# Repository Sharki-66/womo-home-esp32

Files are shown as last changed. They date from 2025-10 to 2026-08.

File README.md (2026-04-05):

# WoMo Home ESP32 – Bordcomputer für's Wohnmobil

> Alle wichtigen Betriebsdaten auf einen Blick – immer wissen, was im Fahrzeug los ist.

## 🚐 Worum geht es?

Wer mit dem Wohnmobil unterwegs ist, kennt das Problem: Wie viel Gas ist noch in der Flasche? Reicht der Strom? Ist der Frischwassertank bald leer? Wie kalt wird es draußen über Nacht? Die serienmäßigen Anzeigen im Fahrzeug sind oft ungenau, schlecht ablesbar oder schlicht nicht vorhanden.

**WoMo Home** ersetzt das klassische EBL-Panel durch ein selbstgebautes System, das alle Betriebsdaten des Wohnmobils erfasst, intelligent aufbereitet und auf einem 7-Zoll-Touchdisplay darstellt – jederzeit aktuell, übersichtlich und von überall im Fahrzeug erreichbar.

## 🎯 Was wird überwacht?

### Energie
- **Bordbatterie & Starterbatterie** – Spannung, Ladezustand
- **Landstrom** – Erkennung, ob 230V angeschlossen sind
- **12V-Bordnetz** – Ein/Aus per Touch, Übersicht aller Verbraucher

### Gas
- **Füllstandsmessung per Waage** – Zwei Gasflaschen, Anzeige in kg und Prozent
- **Verbrauchsberechnung** – Hochrechnung „Wie lange reicht das Gas noch?" auf Basis der letzten Stunden
- **Flaschenwechsel-Erkennung** – Automatisches Zurücksetzen beim Tausch

### Wasser
- **Frischwasser** und **Grauwasser** – Pegelstand in Prozent und Litern
- **Verbrauchstrend** – Restlaufzeit-Prognose

### Klima & Umgebung
- **Innenraumklima** – Temperatur, Luftfeuchte, Luftqualität (IAQ)
- **Außenklima** – Temperatur, Luftfeuchte, Luftdrucktrend
- **Wettervorhersage** – (todo) Aktuelles Wetter und 3-Tage-Prognose vom Internet
- **Unwetterwarnungen** – Automatisch vom europäischen Meteoalarm-System

### Navigation & Lage
- **GPS-Position** – Standort, Geschwindigkeit, Höhe über dem Router
- **Kompass & Neigung** – Fahrzeugausrichtung, Pitch/Roll (Nivellierung beim Aufstellen)
- **Reverse Geocoding** – Automatische Ortsbestimmung (z. B. „Berchtesgaden, Bayern")

### Konnektivität
- **WLAN** – Verbindung zu Campingplatz-Netzen oder Hotspots
- **LTE** – Mobiles Internet über den Router
- **Hotspot** – Eigenes WLAN für alle Geräte im Fahrzeug
- Steuerung und Statusanzeige direkt am Touchscreen

## 🏗️ Wie ist das System aufgebaut?

Das System besteht aus drei Komponenten:

**Sensorboard** – Ein kleiner Mikrocontroller, der sämtliche Sensoren und Aktoren bedient: Waagen, Temperatursensoren, Batteriespannungen, Tankpegel, Kompass. Er sitzt versteckt hinter dem EBL-Schrank und ersetzt dort das originale Anzeigepanel.

**Touchdisplay** – Ein 7-Zoll-Farbbildschirm mit Touch, eingebaut an einer gut sichtbaren Stelle. Hier laufen alle Informationen zusammen und werden grafisch aufbereitet. Über den Touchscreen lassen sich auch Funktionen steuern (Bordnetz ein/aus, Radio, WLAN).

**Router** – Hier ein Teltonika RUTX11 sorgt für die Verbindung zur Außenwelt: LTE-Internet unterwegs, WLAN auf dem Campingplatz, GPS-Ortung und ein eigener Hotspot für Laptops und Smartphones an Bord. Wurde gewählt wegen der Anschlußmöglichkeiten der Antennen auf dem Womo Dach.

Sensorboard und Display kommunizieren über einen RS485-Bus

## 💡 Warum selbst bauen?

- **Genauigkeit** – Die Gasflaschen-Waage zeigt den Füllstand in Gramm statt „irgendwo zwischen halb und voll". Die Tankpegel werden kalibriert statt geschätzt.
- **Alles an einem Ort** – Kein Aufstehen mehr, um am EBL-Panel nachzuschauen. Kein separates Thermometer, keine Extra-App für den Router.
- **Intelligente Prognosen** – Das System rechnet mit: Wie lange reicht das Gas bei aktuellem Verbrauch? Wann ist der Tank leer? Wie entwickelt sich der Luftdruck?
- **Offenes System** – Komplett Open Source auf ESP32-Basis. Erweiterbar, anpassbar, reparierbar. Kein Cloud-Zwang, keine Abo-Kosten.
- **Robustheit** – Industriekomponenten (RS485, Metallgehäuse-Router), für den 12V-Betrieb ausgelegt. Funktioniert auch ohne Internet.
- **Weil es Spass macht und so noch nicht gibt.**

## 📁 Projektstruktur

```
womo-home-esp32/
├── firmware/
│   ├── display/            ← Firmware für das Touchdisplay
│   └── sensorboard/        ← Firmware für das Sensorboard
├── hardware/
│   ├── schematics/          ← Schaltpläne
│   └── datasheets/          ← Datenblätter der Komponenten
├── docs/                    ← Ausführliche Dokumentation
└── tests/                   ← Einzelne Hardware-Tests
```

Technische Details (Pinbelegungen, Protokoll, Build-Anleitung) finden sich in den jeweiligen Unterordnern und in [docs/README.md](docs/README.md).

## 🔧 Entwicklung

Das Projekt nutzt das [Espressif ESP-IDF](https://docs.espressif.com/projects/esp-idf/en/stable/esp32s3/get-started/) Framework. Für jeden Firmware-Teil gibt es einen eigenen VS Code Workspace mit vorkonfigurierten Build/Flash/Monitor-Tasks:

- `womo-sensor.code-workspace` – Sensorboard-Entwicklung
- `womo-display.code-workspace` – Display-Entwicklung

**!!! Der gesammte Code wurde im Vibe Coding erzeugt !!!**

## 📜 Lizenz

Privates Projekt. Siehe [LICENSE](LICENSE).

## 📸 Aufbau-Fotos (Feb 2026)

| Display (Vorderseite) | Sensorboard (Rückseite) |
|---|---|
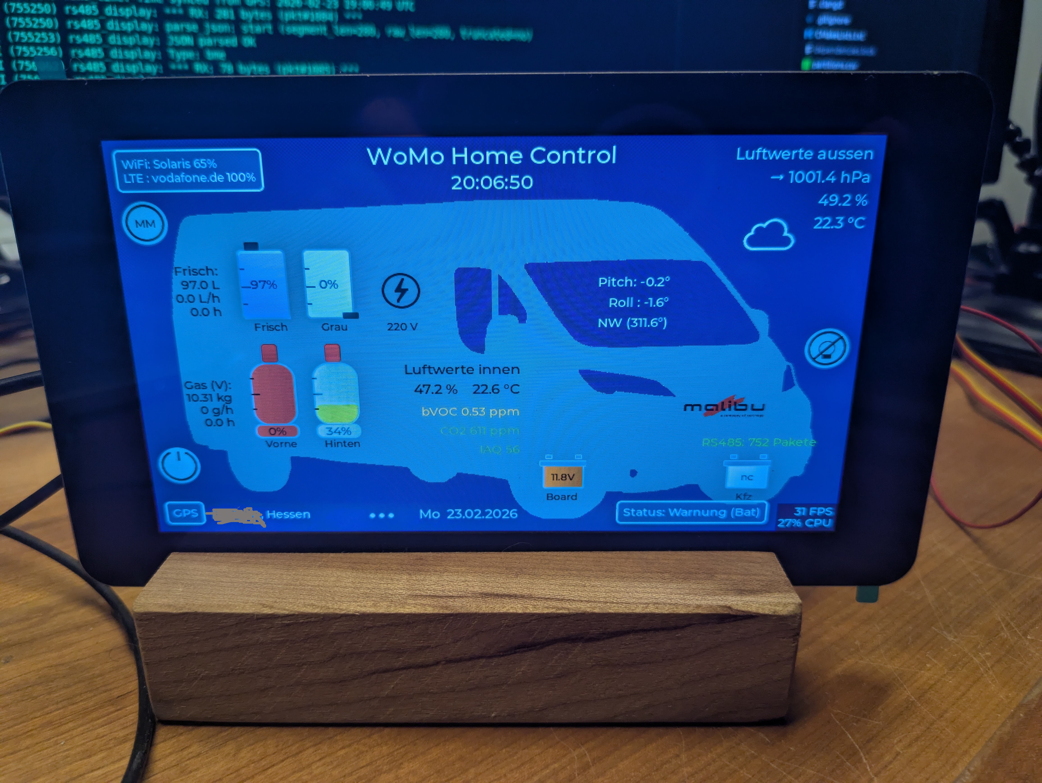
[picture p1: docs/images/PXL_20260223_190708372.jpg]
Display Vorderseite
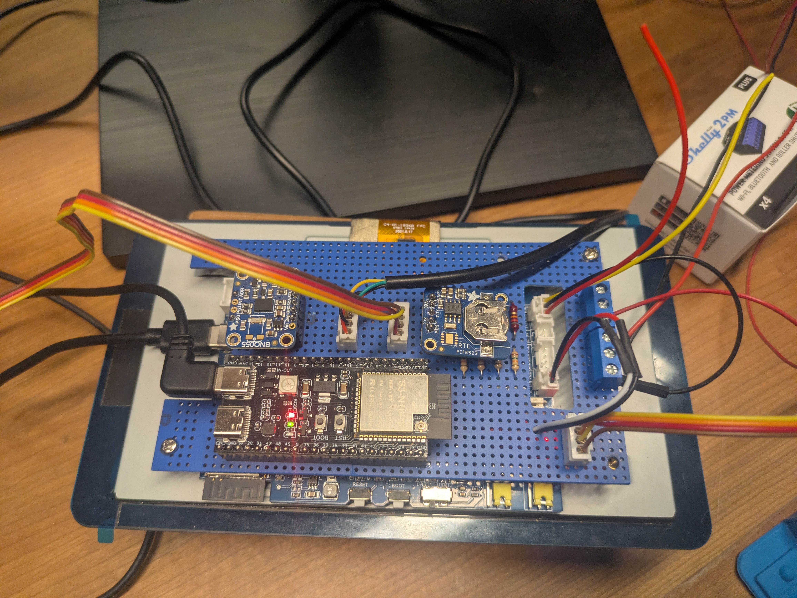
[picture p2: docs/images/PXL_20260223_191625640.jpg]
Sensorboard Rückseite
|  |  |

## 🖥️ Display-Screenshots

| Nacht-Ansicht | GPS |
|---|---|
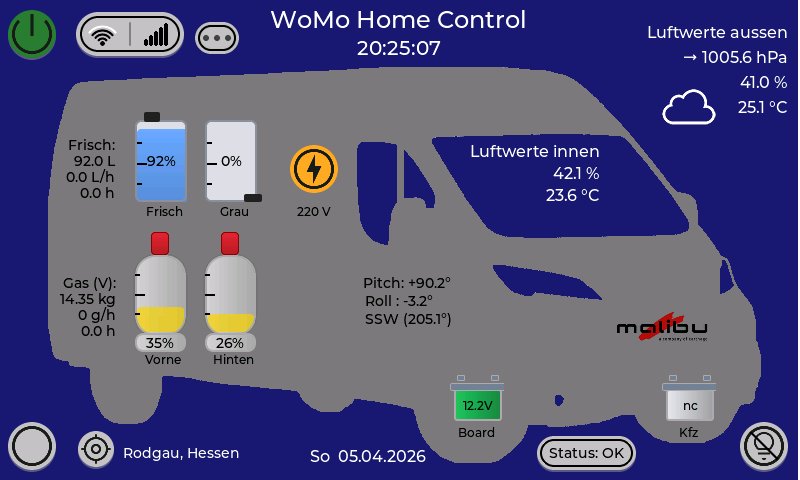
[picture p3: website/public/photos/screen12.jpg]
Nacht-Ansicht
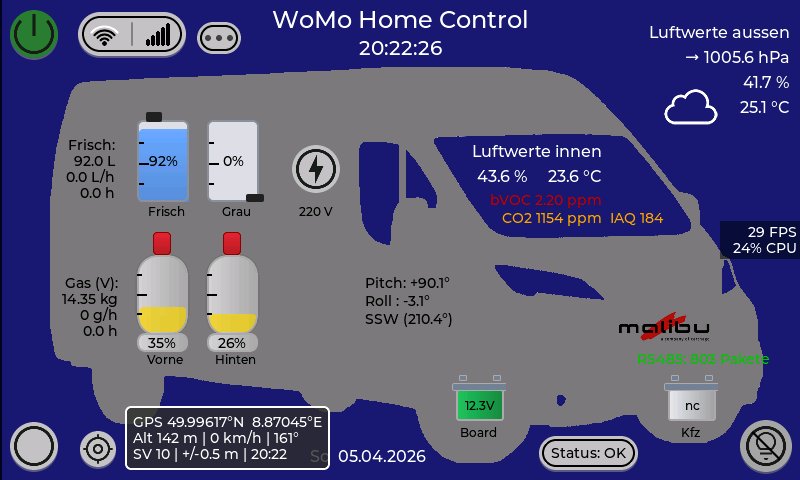
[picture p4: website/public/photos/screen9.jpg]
GPS
|  |  |

| Wetter | Einstellungen |
|---|---|
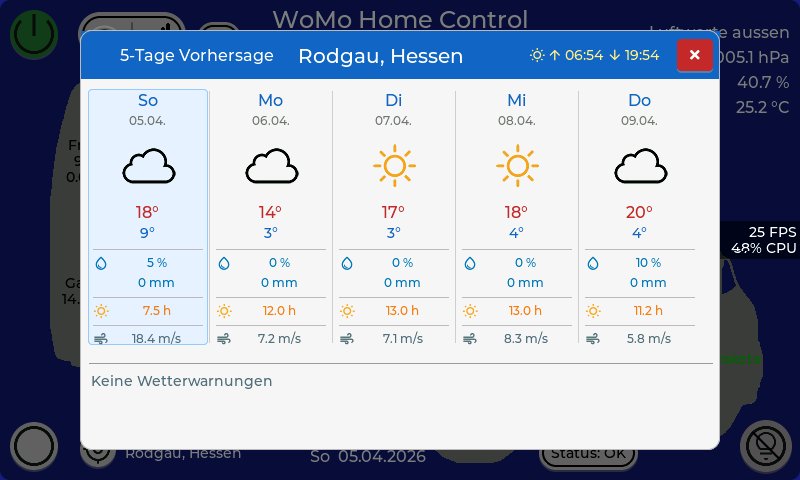
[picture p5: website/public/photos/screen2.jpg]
Wetter
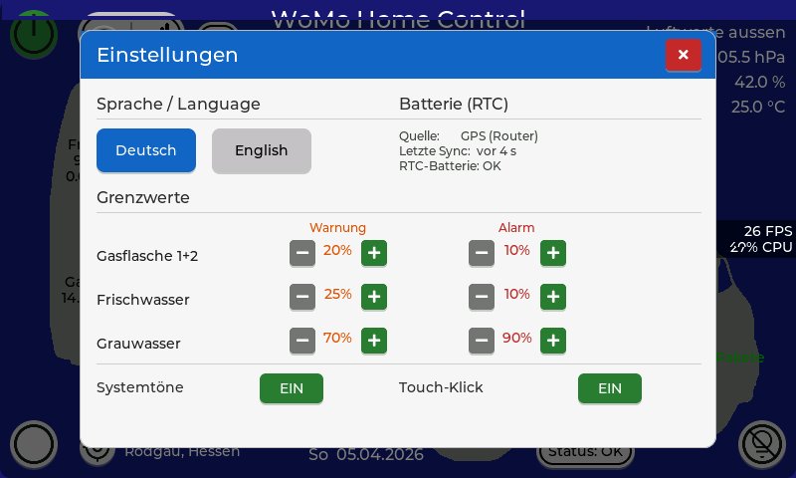
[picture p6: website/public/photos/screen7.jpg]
Einstellungen
|  |  |

| Gas wechseln | Nivellieren |
|---|---|
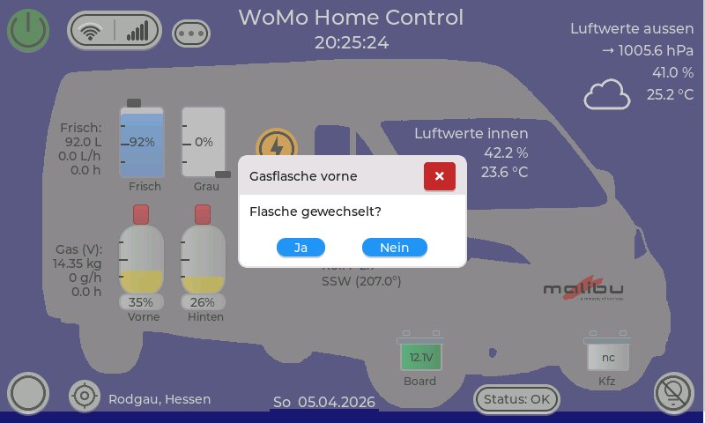
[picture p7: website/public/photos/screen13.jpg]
Gas wechseln
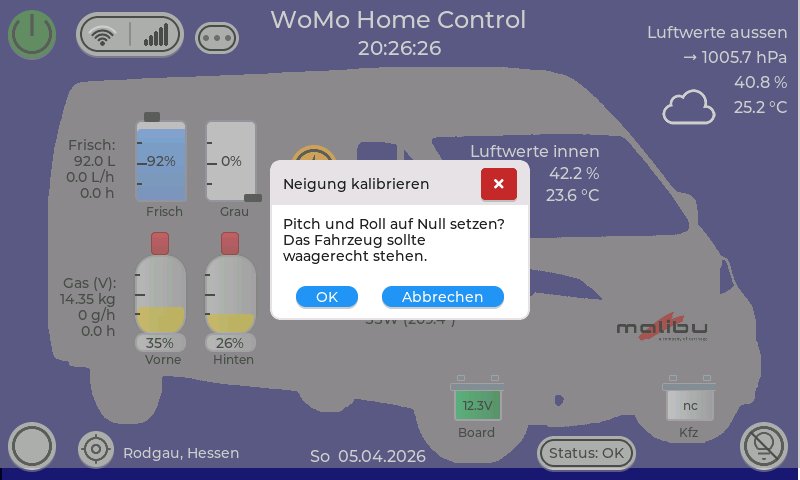
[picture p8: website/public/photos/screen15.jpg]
Nivellieren
|  |  |

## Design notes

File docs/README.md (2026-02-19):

# Dokumentation – WoMo Home ESP32

## Hardware

| Dokument | Beschreibung |
|---|---|
| [ESP32-S3-Touch-LCD-7](hardware/esp32-s3-touch-lcd-7.md) | Waveshare Display-Board (800×480, GT911 Touch) |
| [LCD-Spezifikationen](hardware/WAVESHARE_ESP32_S3_LCD_SPECS.md) | Display-Panel, RGB-Interface, Timing |
| [ESP32-S3 Modul-Specs](hardware/WAVESHARE_ESP32_S3_SPECS.md) | ESP32-S3-WROOM-1, Pinout, PSRAM |
| [Verifizierte Specs](hardware/WAVESHARE_ESP32_S3_VERIFIED_SPECS.md) | Aus Demo-Code bestätigte Werte |

## Firmware

| Dokument | Beschreibung |
|---|---|
| [Sensorboard README](../firmware/sensorboard/README.md) | Hardware, Pins, RS485-Protokoll, NVS, Projektstruktur |
| [Display README](../firmware/display/README.md) | Hardware, Funktionen, Externe APIs, Projektstruktur |

## System

| Komponente | Hardware | Funktion |
|---|---|---|
| **Display** | Waveshare ESP32-S3-Touch-LCD-7 | LVGL-GUI, Touch, RS485-Empfang, Router-Anbindung |
| **Sensorboard** | Heemol ESP32-S3 N16R8 DevKitC-1 | Sensoren (BME680, BNO055, HX711, ADC), RS485-Sender |
| **Router** | Teltonika RUTX11 | WLAN, LTE, GNSS, Hotspot |

Kommunikation: Display ↔ Sensorboard per RS485 (JSON, 115200 8N1).
Router wird vom Display per HTTP/UCI angesprochen.

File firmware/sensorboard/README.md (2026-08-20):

# WoMoHome Sensorboard Firmware

ESP-IDF v5.5.2 · ESP32-S3-WROOM-1 (N16R8)

## Hardware

| Komponente | Beschreibung | Bus / Pin |
|---|---|---|
| **MCU** | Heemol ESP32-S3 N16R8 DevKitC-1 | — |
| **IMU** | BNO055 – Lage, Kompass, Kalibrierung | I2C 0x28 |
| **Klima innen** | BME680 – Temp, Feuchte, Druck, IAQ (BSEC 3.3V) | I2C 0x76 |
| **Klima außen** | BME280 oder BME260 – Temp, Feuchte, Druck, Trend (1h/3h) | I2C 0x77 |
| **Gasfüllstand** | HX711 – 2× Wägezelle (Kanal A + B) | DOUT=GPIO47, SCK=GPIO45 |
| **GasBee** | BLE-Gaswaage (ESP32-C3) – NimBLE Central, Auto-Reconnect | BLE |
| **INA226** | Strom-/Leistungsmessung Hauptleitung (Vbus 0–36V, ±81,92mV Shunt) | I2C 0x40 |
| **Batterien** | 2× ADC mit Spannungsteiler | Kfz=GPIO4, Board=GPIO5 |
| **Tanks** | 2× Votronic kapazitiv (0–1V) | Frisch=GPIO1 (100L), Grau=GPIO2 (92L) |
| **RTC** | PCF8523 – Echtzeituhr | I2C 0x68 |
| **RS485** | MAX3485, Half-Duplex, 57600 8N1 | TX=GPIO9, RX=GPIO10, DE=GPIO8 |
| **I2C** | 100 kHz, interne Pull-ups | SDA=GPIO16, SCL=GPIO15 |
| **RGB-LED** | WS2812 (onboard) | GPIO48 |

### Steuer-/Sense-GPIOs

| GPIO | Funktion | Richtung |
|---|---|---|
| 7  | Display 5V (P-MOSFET Q4: LOW=ein, Hi-Z=aus) | Ausgang |
| 11 | 12V Bordnetz EIN (bistabiles Relais, Puls) | Ausgang |
| 12 | 12V Bordnetz AUS (bistabiles Relais, Puls) | Ausgang |
| 13 | Multimedia Power (N-MOSFET, HIGH=ein) | Ausgang |
| 14 | 12V Bordnetz Feedback | Eingang |
| 21 | 230V AC Sense | Eingang |

### Spannungsteiler (ADC)
Alle Batterie-/Sense-Kanäle: **100 kΩ / 22 kΩ** Teiler → Faktor 122/22.
- Batterien: 12V → ~2,17V am ADC (BZV55B3V3 Zener-Schutz)
- Tanks: Votronic 0–1V → direkt am ADC, 0–1000 mV = 0–100%
- Nicht angeschlossen: < 1V → `nc=true`

## RS485-Protokoll (Topic-basiert, v2)
CRLF-terminierte ASCII-JSON-Zeilen. Round-Robin, max. 1 Topic pro 100 ms. Nach `display_ready`: Initial-Burst aller Topics sofort.

| Topic | Intervall | Felder |
|---|---|---|
| `hello` | bis ready | `fw`, `board`, `uptime`, `ts` |
| `hb` | 30 s | `uptime`, `ts`, `heap` |
| `ctrl` | 2 s | `pwr_on`, `radio_on`, `ac_present`; optional: `rtc_bat_low`, `rtc_bat_switched` |
| `imu` | 5 s | `yaw_deg`, `pitch_deg`, `roll_deg`, `hdg`, `cal:{sys,gyro,acc,mag}`, `calibrated`, `ts` |
| `bat` | 10 s | `b1`, `b2` (Volt), `nc1`, `nc2` |
| `tank` | 10 s | `t1`, `t2` (%), `nc1`, `nc2`, `t1_l`, `t2_l` (Liter), `t1_rate1h`, `t1_rate2h`, `t1_rest_h`, `t2_rate1h`, `t2_rate2h`, `t2_rest_h` |
| `hx` | 10 s | `a`, `b` (kg, optional), `sum` (optional), `nc`, `ts` |
| `gas` | 10 s | `active`, `net`, `rate1h`, `rate2h`, `rest_h`, `net_a`, `net_b`, `cap_kg`, `pct`, `pct_a`, `pct_b` |
| `bme_in` | 15 s | `chip` (`bme680`/`bme280`/`bme260`/`ruuvi`), `addr`?, `temp_c`, `rh_pct`, `press_hpa`, `ts`; BME680 zusätzlich: `gas_kohm`?, `iaq`, `iaq_acc`, `eco2_ppm`, `bvoc_ppm`; bei Ruuvi-Fallback zusätzlich `batt_mv`? |
| `bme_out` | 15 s | `chip`, `addr`?, `temp_c`, `rh_pct`, `press_hpa`, `ts`, `press_trend_state`?, `press_trend_hpa_h`?, `gas_kohm`?; bei Ruuvi-Fallback zusätzlich `batt_mv`? |
| `elec` | 5 s | `v_bus` (V), `i_a` (A), `p_w` (W), `v_shunt_mv` (mV), `ts`; `nc=true` wenn INA226 nicht gefunden |

**`press_trend_state`-Werte:** `fall_fast` / `fall_slow` / `steady` / `rise_slow` / `rise_fast`
(bevorzugt 3h-Fenster, Fallback 1h; ab 4 bzw. 12 Samples à 15 min verfügbar)

**WiFi-Passwort-Anfrage:** Bei fehlenden WLAN-Zugangsdaten sendet das Sensorboard `type:"wifi_pass_request"` per RS485.

## Web-Dashboard (HTTP, Port 80)

Erreichbar unter `http://Womo-Sensor.local/` nach WiFi-Verbindung mit RUTX11.

| Endpunkt | Methode | Beschreibung |
|---|---|---|
| `/` | GET | Weiterleitung auf `/dashboard.html` |
| `/dashboard.html` | GET | Vollständiges Steuer- und Sensor-Dashboard |
| `/horizon.html` | GET | Horizont-/Parkhilfe-Anzeige |
| `/api/status` | GET | Systemstatus (JSON) |
| `/api/data` | GET | Aktueller Sensor-Snapshot (JSON) |
| `/api/imu` | GET | IMU-Snapshot (JSON) |
| `/api/cmd` | POST | Steuerkommandos (JSON, gleiche `cmd`-Syntax wie RS485) |

Statische Dateien (HTML, PNG, favicon) werden aus der SPIFFS-Partition `storage` → `/spiffs` geladen.

## NVS-Namespaces

| Namespace | Key(s) | Inhalt |
|---|---|---|
| `bno055` | `calib`, `pr_zero` | Kalibrierungsoffsets, Pressure-Zero |
| `bme680` | `press_hist` | Luftdruck-Historie (96 Samples / 24h) |
| `bsec` | `state_in_<addr>_v<n>` | BSEC IAQ State (sensorspezifisch, z.B. `state_in_76_v3`) |
| `gas_state` | `gas` | Gasverbrauch (Raten, Tare, Flaschentausch) |
| `tank_state` | `tank1`, `tank2` | Tank-Verbrauchsraten |
| `wifi_cfg` | `ssid`, `pass` | WLAN-Zugangsdaten (RUTX11) |

> **INA226 Kalibrierung:** `SENSOR_INA226_SHUNT_MOHM` in `sensor_config.h` auf den verbauten Shunt-Widerstand (mΩ) setzen. `SENSOR_INA226_MAX_CURRENT_A` bestimmt die Auflösung (Current_LSB = MAX_CURRENT / 32768 A). Maximale Shuntspannung: ±81,92 mV → I_max = 81,92 mV / R_shunt.

> **BSEC State Version:** Bei Tausch des Indoor-BME680 `SENSOR_BME680_BSEC_STATE_VERSION` in `sensor_config.h` hochzählen, damit kein alter Baseline-State auf den neuen Sensor angewandt wird.

## Projektstruktur

```
main/
├── app_main.c              Startup, Task-Orchestrierung
├── sensor_config.h         Pin-Belegung, Kalibrierung, Konstanten
├── hal/
│   ├── sensor_i2c_bus      I2C-Bus Init
│   └── deep_sleep          Touch-Wakeup, Deep-Sleep
├── sensors/
│   ├── analog_sensor       ADC (Batterien, Tanks), Median-of-3-Mittelung
│   ├── bme680_sensor       BME680/BME280/BME260 + BSEC + Drucktrend
│   ├── bno055_sensor       IMU + Kalibrierung
│   ├── hx711_sensor        Wägezellen (Gas)
│   └── ina226_sensor       INA226 Strom-/Leistungsmessung Hauptleitung
├── network/
│   ├── rs485_modem         JSON-Serialisierung aller Topics, Steuerlogik
│   ├── womo_rs485          UART-Transport, Framing, ACK
│   ├── gasbee_ble_client   NimBLE Central – BLE-Gaswaage GasBee
│   └── wifi/
│       ├── sensor_wifi     STA-Verbindung (RUTX11), NVS-Credentials
│       └── sensor_http     HTTP-Server (Dashboard, Parkhilfe, API)
└── time/
    ├── rtc_pcf8523         RTC-Treiber (PCF8523)
    └── time_sync           NTP + RTC-Sync
```

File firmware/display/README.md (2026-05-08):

# WoMoHome Display Firmware

ESP-IDF v5.5.2 · LVGL v9.5 · ESP32-S3 (Waveshare ESP32-S3-Touch-LCD-7)

## Hardware

| Komponente | Beschreibung |
|---|---|
| **Board** | Waveshare ESP32-S3-Touch-LCD-7 (800×480, RGB565) |
| **MCU** | ESP32-S3-WROOM-1, 16 MB Flash, 8 MB PSRAM (Octal) |
| **Display** | 7" IPS, ST7701 RGB-Interface, Double-Buffer + Direct-Mode |
| **Touch** | GT911 (I2C), CH422G GPIO-Expander für Backlight/Reset |
| **RS485** | RX/TX Sensorboard (JSON, 57600 8N1, Half-Duplex) |
| **SD-Karte** | Hintergrundbilder, optional |

## Funktionen

- **Hauptscreen**: Temperatur (innen/außen), Luftdruck + Trend-Pfeil, Feuchte, Kompass, Neigung
- **Batterien**: 2× Balken mit Spannung, Warnung bei Unterspannung
- **Tanks**: Frischwasser + Grauwasser mit Füllstand, Verbrauchsrate, Restdauer
- **Gas**: 2× Flaschengewicht, aktiver Verbrauch, Restdauer
- **Wetter**: Aktuelles WMO-Symbol + Temperatur (Open-Meteo), Tipp auf Icon → 5-Tage-Vorhersage-Modal; Auto-Popup bei Unwetterwarnungen (Meteoalarm)
- **Sonnenauf-/-untergang**: Berechnung aus GPS-Position (womo_sun_calc), Anzeige im Hauptscreen
- **Konnektivität**: Modal mit AP-Status, WLAN-Scan/Connect, LTE Ein/Aus (Router UCI)
- **Router-LEDs**: Separate Statusanzeige für WLAN/LTE/GPS-Empfang des Routers
- **Steuerung**: 12V Bordnetz + Multimedia per RS485-Kommandos ans Sensorboard
- **Fehler-Management**: Fehler-Stack mit Latching, Quittierung per Touch, Buzzer-Alarm (Warn/Alarm-Ton bei neuen unquittier­ten Fehlern)
- **Einstellungs-Modal**: Schwellwerte für Tank/Batterie/Gas konfigurierbar, Speicherung in NVS
- **Screenshot**: Long-Press unten links → PNG auf SD-Karte
- **Tag/Nacht**: Automatischer Themenwechsel (Sonnenauf-/-untergang), Backlight-Steuerung

## Externe Anbindungen

| Dienst | Zweck | TLS |
|---|---|---|
| Open-Meteo | Aktuelles Wetter + 5-Tage-Vorhersage | ISRG Root X1 (PEM, eingebettet) |
| Nominatim | Reverse Geocoding | ISRG Root X1 (PEM, eingebettet) |
| Meteoalarm | Unwetterwarnungen | GEANT TLS RSA 1 (PEM, eingebettet) |
| Teltonika RUTX11 | WLAN/LTE/GPS-Steuerung | HTTP (LAN) |

## Projektstruktur

```
main/
├── main.c                      Startup, GUI-Update-Loop, Task-Orchestrierung
├── gui/
│   ├── womo_theme              Tag/Nacht-Umschaltung
│   ├── womo_locale             Deutsche Lokalisierung (Datum, Wochentage)
│   ├── womo_fonts_german       6× Montserrat mit dt. Sonderzeichen + Icons
│   ├── womo_battery            Batterie-Widget
│   ├── womo_tank               Tank-Widget
│   ├── womo_gas_bottle         Gas-Flaschen-Widget
│   ├── womo_weather            Wetter-Icon-Mapping (WMO → LVGL)
│   ├── womo_forecast_modal     5-Tage-Vorhersage Modal (Open-Meteo daily)
│   ├── womo_connectivity_modal WLAN/LTE/AP-Steuerung
│   ├── womo_router_leds_modal  Router-LED-Statusanzeige
│   ├── womo_settings_modal     Einstellungs-Modal (Schwellwerte, NVS)
│   └── womo_thresholds         Schwellwert-Verwaltung (NVS-Persistenz)
├── hardware/
│   ├── waveshare_rgb_lcd_port  LCD + Touch + CH422G Init
│   ├── lvgl_port               LVGL Flush, Buffer, Task, Indev
│   └── buzzer                  Piezo-Buzzer (Warn/Alarm-Töne)
├── network/
│   ├── womo_wifi               STA-Verbindung + NVS-Passwort-Speicher (RUTX11)
│   ├── womo_weather_http       Open-Meteo API (aktuell + 5-Tage daily)
│   ├── womo_geocode            Nominatim Reverse Geocoding
│   ├── womo_meteoalarm         Meteoalarm CAP-Feed
│   ├── womo_router_uci         RUTX11 UCI JSON-RPC
│   ├── womo_buzzer_http        HTTP-Endpunkt für externen Buzzer-Trigger
│   ├── womo_http_mutex         TLS-Session-Serialisierung
│   ├── isrg_root_x1_pem.h     Let's Encrypt Root-Zertifikat
│   └── harica_root_pem.h       GEANT TLS RSA 1 (Meteoalarm)
├── rs485/
│   └── womo_rs485_display      RS485-Empfang/Senden, JSON-Parsing, Merge-Snapshot
├── storage/
│   └── womo_sd                 SD-Karten-Zugriff (Hintergrundbilder, Screenshots)
└── time/
    ├── womo_time               SNTP + RTC-Sync
    └── womo_sun_calc           Sonnenauf-/-untergang aus GPS-Koordinaten
```

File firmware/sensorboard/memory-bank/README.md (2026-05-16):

# Memory Bank – WoMoHome Sensorboard

Persistenter Projektkontext für Claude Code Sessions.

## Lesreihenfolge
1. [projectbrief.md](projectbrief.md) – Ziel, Scope, Hardware-Übersicht
2. [productContext.md](productContext.md) – Rolle im Gesamtsystem, Schnittstellen
3. [techContext.md](techContext.md) – Build, Komponenten, GPIO-Besonderheiten, NVS
4. [systemPatterns.md](systemPatterns.md) – Boot-Sequenz, Tasks, Protokoll, Sensor-Muster
5. [activeContext.md](activeContext.md) – Aktueller Branch, offene TODOs, Kalibrierungen
6. [progress.md](progress.md) – Fertig / In Arbeit / Bekannte Probleme

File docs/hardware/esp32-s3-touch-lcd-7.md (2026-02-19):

# ESP32-S3-Touch-LCD-7 (Waveshare)

Kurzübersicht des Boards basierend auf den Waveshare-Wiki-Informationen und den bereits kopierten Inhalten.

## Bilder
- Onboard-Ressourcen (beschriftet): Onboard-Ansicht

## Kernmerkmale
- ESP32-S3-WROOM-1-N16R8 (16 MB Flash, 8 MB PSRAM, 512 KB SRAM, 384 KB ROM), LX7 Dual-Core bis 240 MHz.
- 7" IPS, 800×480, 65k Farben, kapazitiver Touch (5-Punkt, I²C, Interrupt).
- WLAN 2.4 GHz b/g/n, BLE 5 (onboard Antenne).
- Schnittstellen: CAN, RS485, I²C, UART (umschaltbar), TF/SD, USB Full-Speed (OTG), PH2.0 Li-Ion (Boost auf 5 V, Laderegler CS8501).
- CH422G IO-Expander steuert u. a. Backlight, Touch-Reset, SD-CS, USB/CAN-Select.

## Onboard-Ressourcen (Nummern aus der Waveshare-Grafik)
1. ESP32-S3-WROOM-1-N16R8 (8 MB PSRAM, 16 MB Flash)
2. Display-FPC (LCD)
3. Touch-FPC
4. TF/SD-Slot
5. USB Type-C (USB-OTG)
6. USB-UART Type-C
7. UART-Klemmen (gemeinsam mit 6, umschaltbar per Schalter 15)
8. Sensor-Klemme
9. CAN-Klemme
10. I²C-Klemme
11. RS485-Klemme + Backlight-Boost
12. PH2.0 Li-Ion-Eingang (3.7 V), Boost auf 5 V, Ladestrom via R45 konfigurierbar
13. CAN-Abschlusswahl
14. RS485-Abschlusswahl
15. UART-Select (UART1 / UART2)
16. BOOT-Taster
17. RESET-Taster
18. I²C-Level-Translator (3.3 V / 5 V)
19. DONE (Laden fertig)
20. CHG (Ladevorgang)
21. PWR (Power-LED)

## Pinbelegungen (Auszug)
### LCD (RGB + Sync + Backlight)
- VSYNC: GPIO3
- HSYNC: GPIO46
- PCLK: GPIO7
- DE: GPIO5
- Daten: R3–R7 (GPIO1,2,40,41,42), G2–G7 (GPIO39,45,48,47,21), B3–B7 (GPIO14,38,18,17,10)
- Backlight Enable: CH422G EXIO2 (Druckpunkt DISP)

### Touch (I²C)
- TP_IRQ: GPIO4
- TP_SDA: GPIO8
- TP_SCL: GPIO9
- TP_RST: CH422G EXIO1

### USB (OTG/Device)
- USB_D−: GPIO19
- USB_D+: GPIO20
- USB_SEL: CH422G EXIO5 (Low = USB, sonst CAN)

### TF/SD (SPI)
- MOSI: GPIO11
- SCK: GPIO12
- MISO: GPIO13
- SD_CS: CH422G EXIO4 (Low aktiv)

### RS485
- TXD: GPIO15
- RXD: GPIO16
- Auto-DE/RE-Schaltung onboard

### CAN
- CANTX: GPIO20
- CANRX: GPIO19
- CAN_SEL: CH422G EXIO5 (High = CAN, sonst USB)

### I²C (Shared Bus)
- SDA: GPIO8
- SCL: GPIO9
- Nutzung: Touch, CH422G IO-Expander, externe I²C-Buchse

### Stromversorgung
- PH2.0 Li-Ion 3.7 V, Boost auf 5 V (CS8501, ca. 580 mA Standard-Ladestrom; änderbar via R45).
- LEDs: DONE (voll), CHG (Lädt), PWR (Versorgt).

## Hinweise
- Touch-Reset, SD-CS, Backlight und USB/CAN-Select laufen über den CH422G – immer dessen Pegel berücksichtigen.
- USB/CAN teilen sich GPIO19/20; EXIO5 entscheidet den Modus.
- Backlight Enable über EXIO2 (aktiviert/abschaltet Versorgung des Panels).
- Bei eigener Verkabelung: Level-Translator (Punkt 18) kann 3.3 V oder 5 V bereitstellen.

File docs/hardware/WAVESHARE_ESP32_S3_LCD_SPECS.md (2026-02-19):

# Hardware-Spezifikationen - Waveshare ESP32-S3 Touch LCD 7" - 800×480

## 📋 **OFFIZIELLE DOKUMENTATIONS-QUELLEN**

### **Primäre Quellen (Waveshare offiziell)**
- 📄 **Wiki:** https://www.waveshare.com/wiki/ESP32-S3-Touch-LCD-7
- 📥 **Schematic (PDF):** https://www.waveshare.com/w/upload/4/4e/ESP32-S3-Touch-LCD-7_Schematic.pdf
- 📚 **User Manual (PDF):** https://files.waveshare.com/upload/2/2a/ESP32-S3-Touch-LCD-7_User_Manual_EN.pdf
- 🔧 **GitHub Examples:** https://github.com/waveshare/ESP32-S3-Touch-LCD-7
- 🛒 **Product Page:** https://www.waveshare.com/esp32-s3-touch-lcd-7.htm

## ✅ **VERIFIZIERTE HARDWARE-SPEZIFIKATIONEN**

### 📺 **DISPLAY SPEZIFIKATIONEN**

| Spezifikation | Wert |
|---|---|
| **Display Typ** | IPS LCD |
| **Display Controller** | ST7262 |
| **Interface** | RGB (16-bit parallel) |
| **Auflösung** | 800×480 Pixel |
| **Diagonale** | 7 Zoll |
| **Pixel Clock** | 16 MHz |
| **Color Depth** | 16-bit (RGB565) |
| **Data Width** | 16-bit parallel |
| **Viewing Angle** | IPS 170° |

### 👆 **TOUCH CONTROLLER**

| Spezifikation | Wert |
|---|---|
| **Controller IC** | GT911 |
| **Interface** | I2C |
| **Touch Points** | 5-Point Multi-Touch |
| **I2C Address** | 0x5D oder 0x14 |

### 🔌 **ESP32-S3 SPEZIFIKATIONEN**

| Spezifikation | Wert |
|---|---|
| **MCU** | ESP32-S3-WROOM-1-N8R8 |
| **Flash** | 8MB |
| **PSRAM** | 8MB |
| **WiFi** | 802.11 b/g/n |
| **Bluetooth** | Bluetooth 5.0, BLE |
| **USB** | USB-C (Programming + Power) |

## ⚙️ **GPIO PIN-MAPPING**

### **RGB Interface GPIO Pins:**
```c
#define EXAMPLE_LCD_IO_RGB_VSYNC        (GPIO_NUM_3)
#define EXAMPLE_LCD_IO_RGB_HSYNC        (GPIO_NUM_46)
#define EXAMPLE_LCD_IO_RGB_DE           (GPIO_NUM_5)
#define EXAMPLE_LCD_IO_RGB_PCLK         (GPIO_NUM_7)

// RGB Data Lines (16-bit)
#define EXAMPLE_LCD_IO_RGB_DATA0        (GPIO_NUM_14)  // R0
#define EXAMPLE_LCD_IO_RGB_DATA1        (GPIO_NUM_38)  // R1
#define EXAMPLE_LCD_IO_RGB_DATA2        (GPIO_NUM_18)  // R2
#define EXAMPLE_LCD_IO_RGB_DATA3        (GPIO_NUM_17)  // R3
#define EXAMPLE_LCD_IO_RGB_DATA4        (GPIO_NUM_10)  // R4
#define EXAMPLE_LCD_IO_RGB_DATA5        (GPIO_NUM_39)  // G0
#define EXAMPLE_LCD_IO_RGB_DATA6        (GPIO_NUM_0)   // G1
#define EXAMPLE_LCD_IO_RGB_DATA7        (GPIO_NUM_45)  // G2
#define EXAMPLE_LCD_IO_RGB_DATA8        (GPIO_NUM_48)  // G3
#define EXAMPLE_LCD_IO_RGB_DATA9        (GPIO_NUM_47)  // G4
#define EXAMPLE_LCD_IO_RGB_DATA10       (GPIO_NUM_21)  // G5
#define EXAMPLE_LCD_IO_RGB_DATA11       (GPIO_NUM_1)   // B0
#define EXAMPLE_LCD_IO_RGB_DATA12       (GPIO_NUM_2)   // B1
#define EXAMPLE_LCD_IO_RGB_DATA13       (GPIO_NUM_42)  // B2
#define EXAMPLE_LCD_IO_RGB_DATA14       (GPIO_NUM_41)  // B3
#define EXAMPLE_LCD_IO_RGB_DATA15       (GPIO_NUM_40)  // B4
```

### **Touch I2C GPIO Pins:**
```c
#define I2C_MASTER_SCL_IO           9       // I2C Clock
#define I2C_MASTER_SDA_IO           8       // I2C Data
#define I2C_MASTER_NUM              0       // I2C Port 0
#define I2C_MASTER_FREQ_HZ          400000  // 400kHz
#define GPIO_INPUT_IO_4             4       // Touch interrupt pin
```

### **Backlight & Control:**
```c
#define EXAMPLE_PIN_NUM_BK_LIGHT        (-1)    // Hardware-gesteuert
#define EXAMPLE_LCD_IO_RST              (-1)    // Nicht verwendet
#define EXAMPLE_LCD_IO_RGB_DISP         (-1)    // Nicht verwendet
```

## 🛠️ **SOFTWARE-KONFIGURATION**

### **ESP-IDF Version:**
```
ESP-IDF v5.2.0+ (empfohlen)
```

### **LVGL Konfiguration für 800×480:**
```c
#define LVGL_PORT_H_RES             800
#define LVGL_PORT_V_RES             480
#define LVGL_PORT_BUFFER_HEIGHT     100
#define LVGL_PORT_AVOID_TEAR        1
```

### **RGB Interface Timing:**
```c
.timings = {
    .pclk_hz = 16000000,        // 16MHz Pixel Clock
    .h_res = 800,               // Horizontale Auflösung
    .v_res = 480,               // Vertikale Auflösung
    .hsync_pulse_width = 30,
    .hsync_back_porch = 16,
    .hsync_front_porch = 210,
    .vsync_pulse_width = 13,
    .vsync_back_porch = 10,
    .vsync_front_porch = 22,
}
```

## 🔋 **STROMVERSORGUNG**

| Spezifikation | Wert |
|---|---|
| **Input Voltage** | 5V via USB-C |
| **Power Consumption** | ~1.2W (Display an) |
| **Sleep Current** | <10mA |

## 📦 **VERWENDETE BIBLIOTHEKEN**

### **ESP-IDF Komponenten:**
- `esp_lcd_panel_rgb` - RGB LCD Panel Treiber
- `esp_lcd_touch_gt911` - GT911 Touch Controller Treiber
- `driver/i2c` - I2C Treiber für Touch
- `driver/gpio` - GPIO Treiber

### **LVGL Integration:**
- RGB Avoid Tearing implementiert
- Double Buffering für flüssige Animationen
- 800×480 optimierte Widgets

## ✅ **VERIFIKATIONS-STATUS**

| Komponente | Status | Quelle |
|---|---|---|
| **Display Controller (ST7262)** | ✅ Verifiziert | Waveshare Dokumentation |
| **Touch Controller (GT911)** | ✅ Verifiziert | Waveshare Demo Code |
| **Auflösung 800×480** | ✅ Verifiziert | Hardware-Spezifikation |
| **GPIO Pin-Mapping** | ✅ Verifiziert | Schaltplan |
| **ESP-IDF v5.2.0** | ✅ Verifiziert | Offizieller Support |
| **LVGL Integration** | ✅ Verifiziert | Funktionierender Demo |
| **RGB 16-bit Interface** | ✅ Verifiziert | Hardware-Konfiguration |
| **I2C Touch Interface** | ✅ Verifiziert | I2C GT911 Treiber |

---

**DIESE SPEZIFIKATIONEN SIND FÜR DAS LCD 7" 800×480 MODELL VERIFIZIERT!** 🎯

*Erstellt: 26. Oktober 2025*

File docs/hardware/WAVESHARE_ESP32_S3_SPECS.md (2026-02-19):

# Hardware-Spezifikationen - Waveshare ESP32-S3 Touch AMOLED 7"

## 📋 **OFFIZIELLE DOKUMENTATIONS-QUELLEN**

### **Primäre Quellen (Waveshare offiziell)**
- 📄 **Wiki:** https://www.waveshare.com/wiki/ESP32-S3-Touch-AMOLED-7
- 📥 **Schematic (PDF):** https://www.waveshare.com/w/upload/5/51/ESP32-S3-Touch-AMOLED-7_Schematic.pdf
- 📚 **User Manual (PDF):** https://files.waveshare.com/upload/7/79/ESP32-S3-Touch-AMOLED-7_User_Manual_EN.pdf
- 🔧 **GitHub Examples:** https://github.com/waveshare/ESP32-S3-Touch-AMOLED-7
- 🛒 **Product Page:** https://www.waveshare.com/esp32-s3-touch-amoled-7.htm

## ⚠️ **AKTUELLER STATUS DER DOKUMENTATION**

### **Wiki-Status:** ❌ **UNVOLLSTÄNDIG**
- Waveshare Wiki zeigt: "Wiki resources are under urgent production"
- Keine technischen Spezifikationen verfügbar
- Verweis auf Manual Technical Support

### **NEXT STEPS - FAKTEN SAMMELN**

**SOFORT ERFORDERLICH:**
1. ✅ **Schematic PDF herunterladen und analysieren**
   - GPIO Pin-Mapping
   - Display Controller IC identifizieren
   - Touch Controller IC identifizieren
   - SPI/I2C Konfiguration

2. ✅ **User Manual PDF herunterladen und analysieren**
   - Hardware-Spezifikationen
   - Software-Anforderungen
   - Beispiel-Code Referenzen

3. ✅ **GitHub Repository klonen und analysieren**
   - Offizielle Beispiel-Implementierungen
   - Display-Treiber Code
   - Touch-Interface Code
   - Build-Konfiguration

## 🚫 **ENTWICKLUNGS-STOPP BIS VOLLSTÄNDIGE SPEZIFIKATIONEN VORLIEGEN**

**Gemäß DEVELOPMENT_GUIDELINES.md:**
- Keine weitere Code-Entwicklung ohne verifizierte Hardware-Specs
- Keine Annahmen über Display-Controller oder GPIO-Pins
- Keine LVGL-Integration ohne bestätigte Kompatibilität

## 📝 **SPEZIFIKATIONS-CHECKLISTE**

### **Hardware-Komponenten zu identifizieren:**
- [ ] **Display Controller IC** (Modell, Datenblatt)
- [ ] **Touch Controller IC** (Modell, Datenblatt)
- [ ] **Display Auflösung** (exakte Pixel-Werte)
- [ ] **SPI Configuration** (MOSI, MISO, CLK, CS Pins)
- [ ] **I2C Configuration** (SDA, SCL Pins für Touch)
- [ ] **Power Management** (Backlight, Display Power)
- [ ] **GPIO Pin-Mapping** (alle verwendeten Pins)

### **Software-Anforderungen zu klären:**
- [ ] **ESP-IDF Version** (minimale und getestete Version)
- [ ] **LVGL Version** (kompatible Version)
- [ ] **Display Treiber** (welche Library wird verwendet)
- [ ] **Touch Treiber** (welche Library wird verwendet)
- [ ] **Build Dependencies** (zusätzliche Komponenten)

---

**STATUS:** 🔴 **WARTEN AUF VOLLSTÄNDIGE DOKUMENTATION**  
**NÄCHSTER SCHRITT:** PDFs herunterladen und analysieren  
**ENTWICKLUNG:** ⏸️ **PAUSIERT** bis Hardware-Specs verifiziert

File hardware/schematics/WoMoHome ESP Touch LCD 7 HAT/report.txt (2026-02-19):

Hinweis: Verarbeite Symbol "R11:Resistor_SMD:R_0805_2012Metric_Pad1.20x1.40mm_HandSolder".
Hinweis: Verarbeite Symbol "C1:Capacitor_SMD:C_0805_2012Metric_Pad1.18x1.45mm_HandSolder".
Hinweis: Verarbeite Symbol "J10:Connector_PinHeader_2.54mm:PinHeader_1x04_P2.54mm_Horizontal".
Hinweis: Verarbeite Symbol "L1:Inductor_SMD_Wurth:L_Wurth_WE-LQSH-4020".
Hinweis: Verarbeite Symbol "R1:Resistor_SMD:R_0805_2012Metric_Pad1.20x1.40mm_HandSolder".
Hinweis: Verarbeite Symbol "R2:Resistor_SMD:R_0805_2012Metric_Pad1.20x1.40mm_HandSolder".
Hinweis: Verarbeite Symbol "R3:Resistor_SMD:R_0805_2012Metric_Pad1.20x1.40mm_HandSolder".
Hinweis: Verarbeite Symbol "R4:Resistor_SMD:R_0805_2012Metric_Pad1.20x1.40mm_HandSolder".
Hinweis: Verarbeite Symbol "R5:Resistor_SMD:R_0805_2012Metric_Pad1.20x1.40mm_HandSolder".
Hinweis: Verarbeite Symbol "R6:Resistor_SMD:R_0805_2012Metric_Pad1.20x1.40mm_HandSolder".
Hinweis: Verarbeite Symbol "R7:Resistor_SMD:R_0805_2012Metric_Pad1.20x1.40mm_HandSolder".
Hinweis: Verarbeite Symbol "R8:Resistor_SMD:R_0805_2012Metric_Pad1.20x1.40mm_HandSolder".
Hinweis: Verarbeite Symbol "R9:Resistor_SMD:R_0805_2012Metric_Pad1.20x1.40mm_HandSolder".
Hinweis: Verarbeite Symbol "R10:Resistor_SMD:R_0805_2012Metric_Pad1.20x1.40mm_HandSolder".
Hinweis: Verarbeite Symbol "J9:Connector_PinHeader_2.54mm:PinHeader_1x10_P2.54mm_Vertical".
Hinweis: Verarbeite Symbol "R12:Resistor_SMD:R_0805_2012Metric_Pad1.20x1.40mm_HandSolder".
Hinweis: Verarbeite Symbol "R13:Resistor_SMD:R_0805_2012Metric_Pad1.20x1.40mm_HandSolder".
Hinweis: Verarbeite Symbol "R14:Resistor_SMD:R_0805_2012Metric_Pad1.20x1.40mm_HandSolder".
Hinweis: Verarbeite Symbol "SW1:Button_Switch_THT:SW_PUSH_6mm".
Hinweis: Verarbeite Symbol "U1:Package_DIP:DIP-16_W7.62mm".
Hinweis: Verarbeite Symbol "U2:Package_DIP:DIP-8_W7.62mm".
Hinweis: Verarbeite Symbol "U3:WoMoHome:SIM7600X-ESP32".
Hinweis: Verarbeite Symbol "U4:Package_SO:Infineon_PG-DSO-8-43".
Hinweis: Verarbeite Symbol "U5:Package_SO:Infineon_PG-DSO-8-43".
Hinweis: Verarbeite Symbol "U6:Package_SO:Infineon_PG-DSO-8-43".
Hinweis: Verarbeite Symbol "U7:Package_TO_SOT_SMD:TSOT-23-6".
Hinweis: Warnungen insgesamt: 4, Fehler insgesamt: 1.
Hinweis: Verarbeite Symbol "F1:Fuse:Fuse_1210_3225Metric_Pad1.42x2.65mm_HandSolder".
Hinweis: Verarbeite Symbol "C2:Capacitor_SMD:C_0805_2012Metric_Pad1.18x1.45mm_HandSolder".
Hinweis: Verarbeite Symbol "C3:Capacitor_SMD:C_0805_2012Metric_Pad1.18x1.45mm_HandSolder".
Hinweis: Verarbeite Symbol "C4:Capacitor_SMD:C_1206_3216Metric_Pad1.33x1.80mm_HandSolder".
Hinweis: Verarbeite Symbol "C6:Capacitor_SMD:C_1206_3216Metric_Pad1.33x1.80mm_HandSolder".
Hinweis: Verarbeite Symbol "D1:Diode_SMD:D_MiniMELF".
Hinweis: Verarbeite Symbol "D2:Diode_SMD:D_MiniMELF".
Hinweis: Verarbeite Symbol "D3:Diode_SMD:D_MiniMELF".
Hinweis: Verarbeite Symbol "D4:Diode_SMD:D_MiniMELF".
Hinweis: Verarbeite Symbol "D5:Diode_SMD:D_MiniMELF".
Hinweis: Verarbeite Symbol "D6:Diode_SMD:D_MiniMELF".
Hinweis: Verarbeite Symbol "D7:Diode_SMD:D_SMA".
Hinweis: Verarbeite Symbol "J8:TerminalBlock_Phoenix:TerminalBlock_Phoenix_PT-1,5-3-5.0-H_1x03_P5.00mm_Horizontal".
Hinweis: Verarbeite Symbol "J1:Connector_PinHeader_2.54mm:PinHeader_1x04_P2.54mm_Horizontal".
Hinweis: Verarbeite Symbol "J2:Connector_JST:JST_XH_S4B-XH-A-1_1x04_P2.50mm_Horizontal".
Hinweis: Verarbeite Symbol "J3:Connector_JST:JST_XH_S4B-XH-A-1_1x04_P2.50mm_Horizontal".
Hinweis: Verarbeite Symbol "J4:Connector_JST:JST_XH_S4B-XH-A-1_1x02_P2.50mm_Horizontal".
Hinweis: Verarbeite Symbol "J5:Connector_JST:JST_XH_S4B-XH-A-1_1x04_P2.50mm_Horizontal".
Hinweis: Verarbeite Symbol "J6:TerminalBlock_Phoenix:TerminalBlock_Phoenix_PT-1,5-3-5.0-H_1x03_P5.00mm_Horizontal".
Hinweis: Verarbeite Symbol "J7:Connector_Molex:Molex_Micro-Fit_3.0_43045-1000_2x05_P3.00mm_Horizontal".
Footprint F1 von "Connector_JST:JST_XH_S4B-XH-A-1_1x04_P2.50mm_Horizontal" in "Fuse:Fuse_1210_3225Metric_Pad1.42x2.65mm_HandSolder" ändern.

Warnung: Kein Netz für Komponente F1 Pad 3 gefunden (kein Pin 3 in Symbol).
Warnung: Kein Netz für Komponente F1 Pad 4 gefunden (kein Pin 4 in Symbol).
Warnung: Kein Netz für Komponente J4 Pad 4 gefunden (kein Pin 4 in Symbol).
Warnung: Kein Netz für Komponente J4 Pad 3 gefunden (kein Pin 3 in Symbol).
Fehler: Kann J4 nicht aktualisieren (Footprint "Connector_JST:JST_XH_S4B-XH-A-1_1x02_P2.50mm_Horizontal" nicht gefunden).

Hinweis: Warnungen insgesamt: 4, Fehler insgesamt: 1.

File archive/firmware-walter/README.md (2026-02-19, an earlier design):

# Walter Firmware (ESP32-S3 Sensor Hub)

This project contains the dedicated firmware for the "Walter" ESP32-S3 module.
It will host the sensor stack (BNO055, ADS1115, …) and forward measurements to
the display controller over RS-485.

## Build & Flash

```powershell
cd firmware-walter
idf.py set-target esp32s3
idf.py build flash monitor
```

Make sure to select the COM port of the Walter board when flashing or monitoring.

## Next Steps

- Add drivers for the BNO055 IMU and ADS1115 ADC.
- Implement the RS-485 transport and frame format.
- Expose configuration via Kconfig (GPIO assignments, baud rate, polling interval).
- Provide a simple command interface for calibration and diagnostics.

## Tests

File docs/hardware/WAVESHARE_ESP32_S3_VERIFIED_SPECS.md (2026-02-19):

# Hardware-Spezifikationen - Waveshare ESP32-S3 AMOLED 7" (VERIFIZIERT)

## ✅ **OFFIZIELLE HARDWARE-SPEZIFIKATIONEN**

### **Quelle:** Waveshare offizieller Demo Code  
**Pfad:** `docs/software/ESP32-S3-Touch-LCD-7-Demo/ESP-IDF/08_lvgl_Porting/`  
**Status:** ✅ **VERIFIZIERT aus offiziellem Code**

---

## 📺 **DISPLAY CONTROLLER**

| Spezifikation | Wert |
|---|---|
| **Controller IC** | ST7701 |
| **Interface** | RGB (16-bit parallel) |
| **Auflösung** | Definiert in `LVGL_PORT_H_RES` x `LVGL_PORT_V_RES` |
| **Pixel Clock** | 16 MHz |
| **Color Depth** | 16-bit (RGB565) |
| **Data Width** | 16-bit parallel |

### **RGB Interface GPIO Pins:**
```c
#define EXAMPLE_LCD_IO_RGB_VSYNC        (GPIO_NUM_3)
#define EXAMPLE_LCD_IO_RGB_HSYNC        (GPIO_NUM_46)
#define EXAMPLE_LCD_IO_RGB_DE           (GPIO_NUM_5)
#define EXAMPLE_LCD_IO_RGB_PCLK         (GPIO_NUM_7)

// RGB Data Lines (16-bit)
#define EXAMPLE_LCD_IO_RGB_DATA0        (GPIO_NUM_14)
#define EXAMPLE_LCD_IO_RGB_DATA1        (GPIO_NUM_38)
#define EXAMPLE_LCD_IO_RGB_DATA2        (GPIO_NUM_18)
#define EXAMPLE_LCD_IO_RGB_DATA3        (GPIO_NUM_17)
#define EXAMPLE_LCD_IO_RGB_DATA4        (GPIO_NUM_10)
#define EXAMPLE_LCD_IO_RGB_DATA5        (GPIO_NUM_39)
#define EXAMPLE_LCD_IO_RGB_DATA6        (GPIO_NUM_0)
#define EXAMPLE_LCD_IO_RGB_DATA7        (GPIO_NUM_45)
#define EXAMPLE_LCD_IO_RGB_DATA8        (GPIO_NUM_48)
#define EXAMPLE_LCD_IO_RGB_DATA9        (GPIO_NUM_47)
#define EXAMPLE_LCD_IO_RGB_DATA10       (GPIO_NUM_21)
#define EXAMPLE_LCD_IO_RGB_DATA11       (GPIO_NUM_1)
#define EXAMPLE_LCD_IO_RGB_DATA12       (GPIO_NUM_2)
#define EXAMPLE_LCD_IO_RGB_DATA13       (GPIO_NUM_42)
#define EXAMPLE_LCD_IO_RGB_DATA14       (GPIO_NUM_41)
#define EXAMPLE_LCD_IO_RGB_DATA15       (GPIO_NUM_40)
```

---

## 👆 **TOUCH CONTROLLER**

| Spezifikation | Wert |
|---|---|
| **Controller IC** | GT911 |
| **Interface** | I2C |
| **I2C Address** | Standard GT911 (0x5D oder 0x14) |

### **Touch I2C GPIO Pins:**
```c
#define I2C_MASTER_SCL_IO           9       // I2C Clock
#define I2C_MASTER_SDA_IO           8       // I2C Data
#define I2C_MASTER_NUM              0       // I2C Port 0
#define I2C_MASTER_FREQ_HZ          400000  // 400kHz
```

### **Touch Control Pins:**
```c
#define EXAMPLE_PIN_NUM_TOUCH_RST       (-1)    // Not used
#define EXAMPLE_PIN_NUM_TOUCH_INT       (-1)    // Not used
#define GPIO_INPUT_IO_4                 4       // Touch interrupt pin
```

---

## ⚙️ **SOFTWARE-KONFIGURATION**

### **ESP-IDF Version:**
```
ESP-IDF v5.2.0 (verifiziert aus Demo)
```

### **ESP32-S3 Konfiguration:**
```c
CONFIG_IDF_TARGET="esp32s3"
CONFIG_ESP_DEFAULT_CPU_FREQ_MHZ_240=y
CONFIG_SPIRAM=y
CONFIG_SPIRAM_MODE_OCT=y
CONFIG_SPIRAM_SPEED_80M=y
CONFIG_ESPTOOLPY_FLASHSIZE_8MB=y
```

### **LVGL Konfiguration:**
```c
CONFIG_LV_COLOR_SCREEN_TRANSP=y
CONFIG_LV_MEM_CUSTOM=y
CONFIG_LV_USE_PERF_MONITOR=y
CONFIG_LV_ATTRIBUTE_FAST_MEM_USE_IRAM=y
CONFIG_LV_FONT_MONTSERRAT_12=y
CONFIG_LV_FONT_MONTSERRAT_16=y
CONFIG_LV_FONT_MONTSERRAT_20=y
CONFIG_LV_FONT_MONTSERRAT_24=y
```

---

## 🔧 **HARDWARE-FEATURES**

### **Backlight Control:**
```c
#define EXAMPLE_PIN_NUM_BK_LIGHT        (-1)    // Nicht verwendet/Hardware-gesteuert
#define EXAMPLE_LCD_BK_LIGHT_ON_LEVEL   (1)
```

### **Reset Pin:**
```c
#define EXAMPLE_LCD_IO_RST              (-1)    // Nicht verwendet
```

### **Display Enable:**
```c
#define EXAMPLE_LCD_IO_RGB_DISP         (-1)    // Nicht verwendet
```

---

## 📚 **VERWENDETE BIBLIOTHEKEN**

### **ESP-IDF Komponenten:**
- `esp_lcd_panel_rgb` - RGB LCD Panel Treiber
- `esp_lcd_touch_gt911` - GT911 Touch Controller Treiber
- `driver/i2c` - I2C Treiber für Touch
- `driver/gpio` - GPIO Treiber

### **LVGL Integration:**
- Offizielle ESP-IDF LVGL Port
- RGB Avoid Tearing implementiert
- Demo Widgets verfügbar

---

## ✅ **VERIFIKATIONS-STATUS**

| Komponente | Status | Quelle |
|---|---|---|
| **Display Controller (ST7701)** | ✅ Verifiziert | Waveshare Demo Code |
| **Touch Controller (GT911)** | ✅ Verifiziert | Waveshare Demo Code |
| **GPIO Pin-Mapping** | ✅ Verifiziert | waveshare_rgb_lcd_port.h |
| **ESP-IDF v5.2.0** | ✅ Verifiziert | sdkconfig.defaults |
| **LVGL Integration** | ✅ Verifiziert | Funktionierender Demo |
| **RGB 16-bit Interface** | ✅ Verifiziert | Hardware-Konfiguration |
| **I2C Touch Interface** | ✅ Verifiziert | I2C GT911 Treiber |

---

**DIESE SPEZIFIKATIONEN SIND 100% VERIFIZIERT UND EINSATZBEREIT!** 🎯

*Aktualisiert: 26. Oktober 2025*  
*Status: Hardware-Spezifikationen vollständig verifiziert*

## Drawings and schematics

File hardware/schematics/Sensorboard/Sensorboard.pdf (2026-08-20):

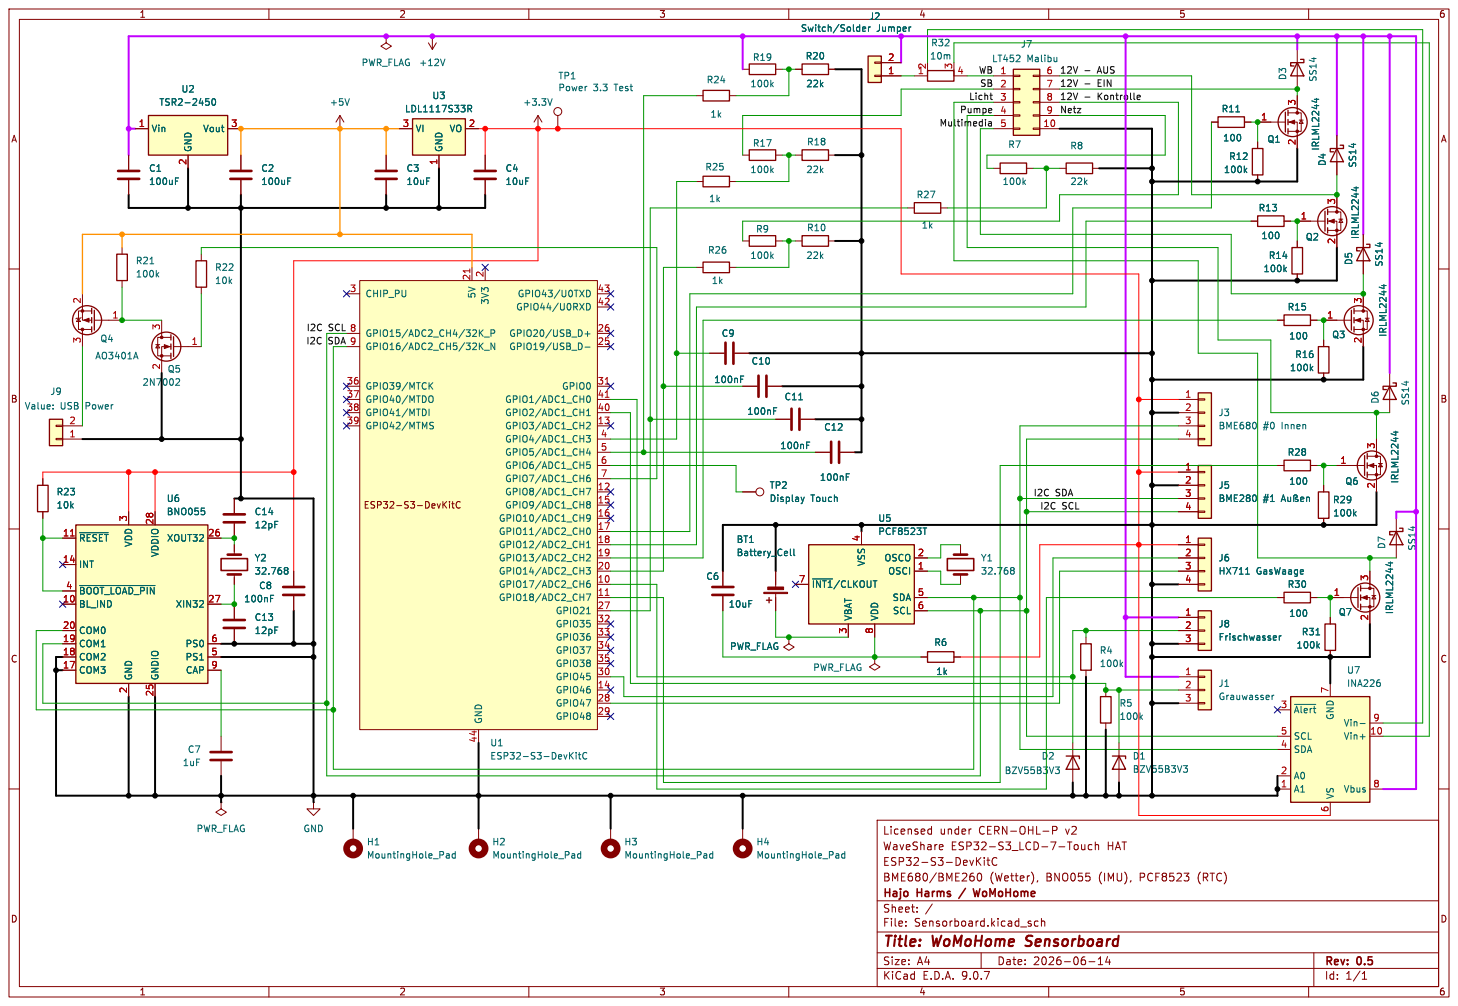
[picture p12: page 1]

I2C SDA Netz Multimedia PumpeWB

2 CHIP_PU 3 GPIO15/ADC2_CH4/32K_P 8 GPIO16/ADC2_CH5/32K_N 9 GPIO39/MTCK 36 GPIO40/MTDO 37 GPIO41/MTDI 38 5V 21 GPIO20/USB_D+ 26 GPIO19/USB_D- 25 GPIO0 31 GPIO3/ADC1_CH2 13 GPIO4/ADC1_CH3 4 GPIO5/ADC1_CH4 5 GPIO6/ADC1_CH5 6 GPIO7/ADC1_CH6 7 GPIO8/ADC1_CH7 12 GPIO9/ADC1_CH8 15 GPIO10/ADC1_CH9 16 GPIO11/ADC2_CH0 17 GPIO12/ADC2_CH1 18 GPIO14/ADC2_CH3 20 GPIO17/ADC2_CH6 10 GPIO18/ADC2_CH7 11 GPIO21 27 GPIO35 32 GPIO36 33 GPIO37 34 GPIO38 35 GPIO45 30 GPIO47 28 GPIO48 29 U1ESP32-S3-DevKitC

Id: 1/1 Title: WoMoHome Sensorboard

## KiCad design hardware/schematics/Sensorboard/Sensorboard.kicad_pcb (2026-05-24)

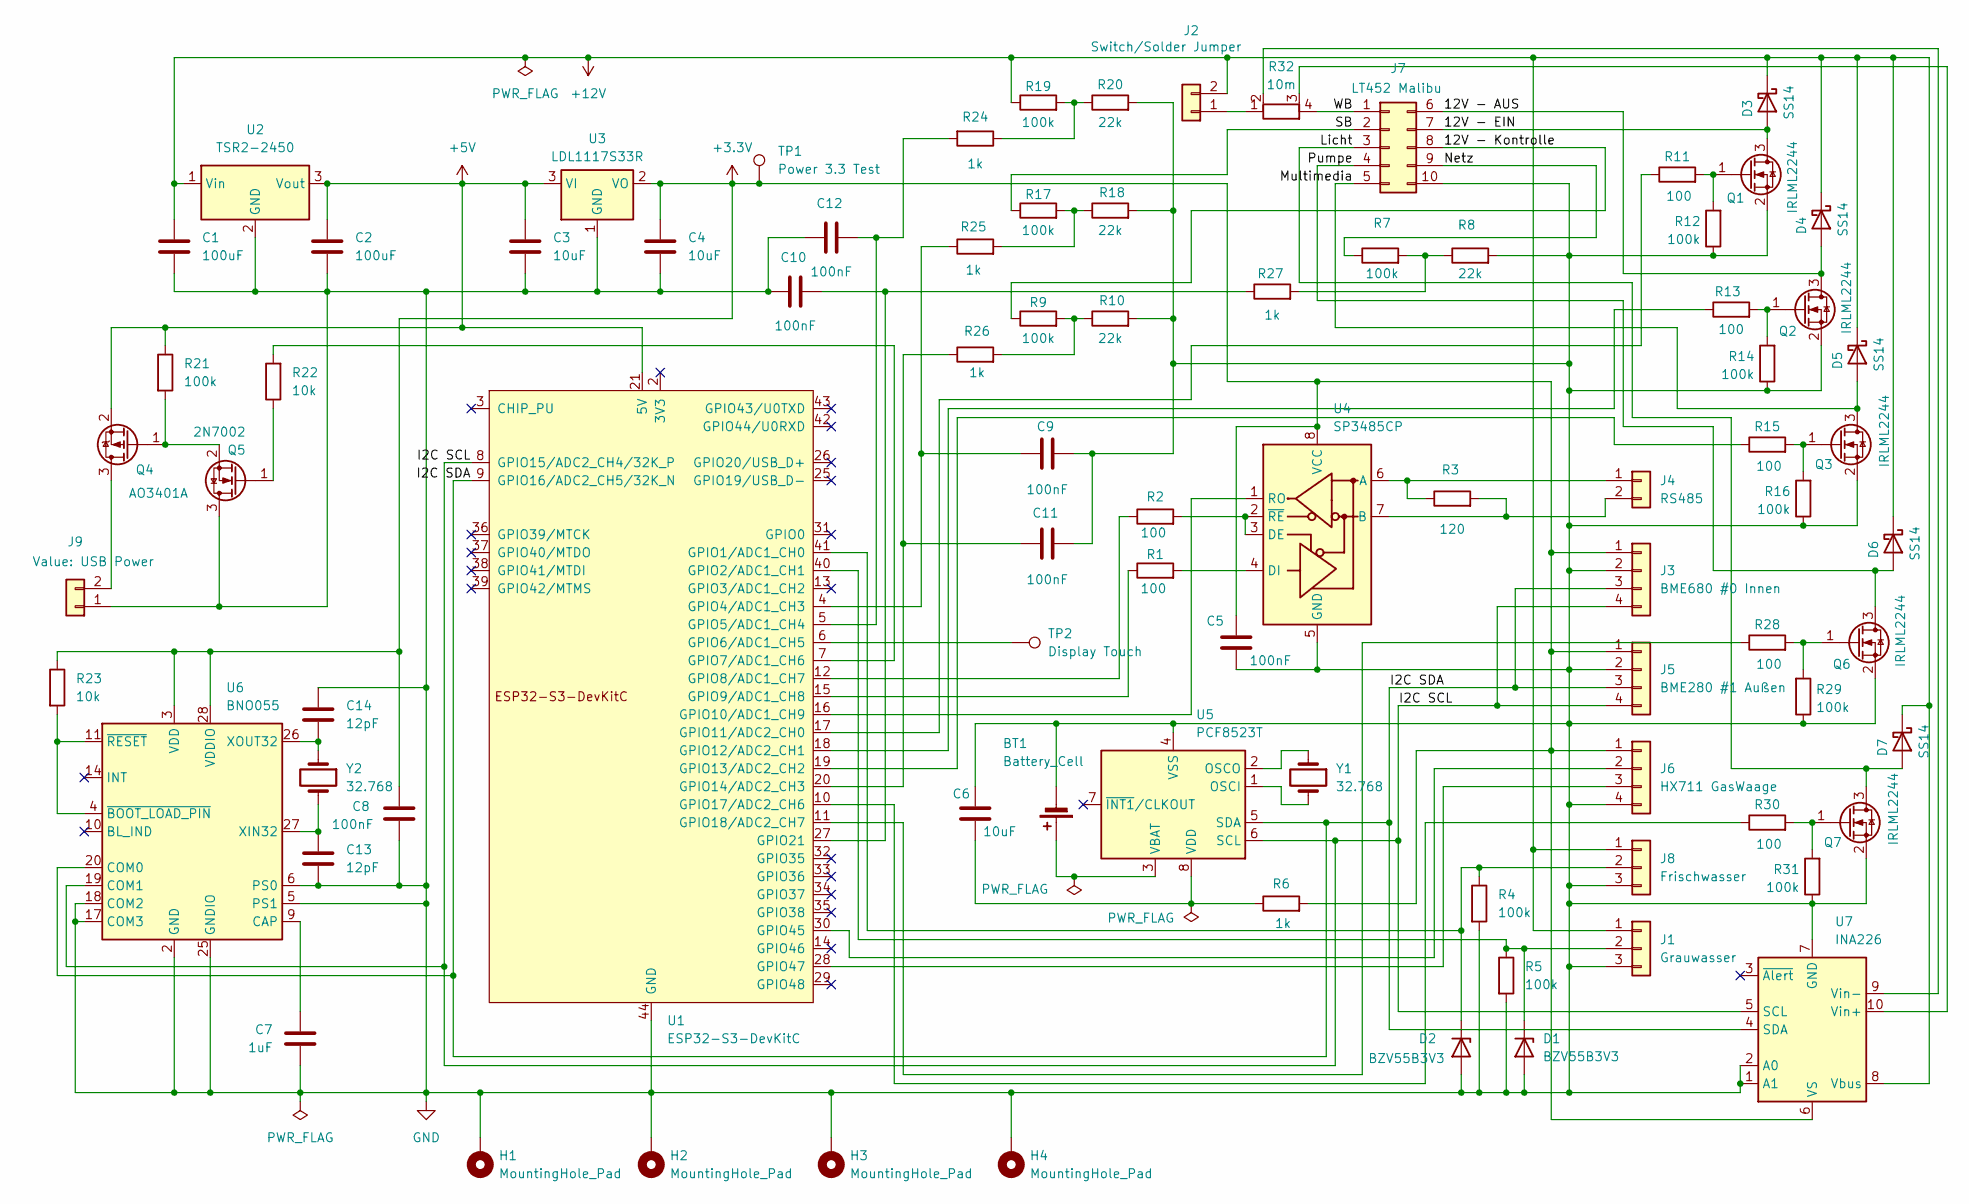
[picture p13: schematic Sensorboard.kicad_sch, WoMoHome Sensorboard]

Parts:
BT1: Battery_Cell; BatteryHolder_Keystone_3000_1x12mm
C1, C2: 100uF; CP_Radial_D5.0mm_P2.50mm
C3, C4, C6: 10uF; C_0402_1005Metric
C5, C8, C9, C10, C11, C12: 100nF; C_0402_1005Metric
C7: 1uF; C_0402_1005Metric
C13, C14: 12pF; C_0402_1005Metric
D1, D2: BZV55B3V3; D_MiniMELF
D3, D4, D5, D6, D7: SS14; D_SMA
H1, H2, H3, H4: MountingHole_Pad; MountingHole_3.2mm_M3_Pad
J1: Grauwasser; JST_XH_B3B-XH-A_1x03_P2.50mm_Vertical
J2: Switch/Solder Jumper; PinHeader_1x02_P2.54mm_Vertical
J3: BME680 #0 Innen; JST_XH_B4B-XH-A_1x04_P2.50mm_Vertical
J4: RS485; JST_XH_B2B-XH-A_1x02_P2.50mm_Vertical
J5: BME280 #1 Außen; JST_XH_B4B-XH-A_1x04_P2.50mm_Vertical
J6: HX711 GasWaage; JST_XH_B4B-XH-A_1x04_P2.50mm_Vertical
J7: LT452 Malibu; Molex_Micro-Fit_3.0_43045-1012_2x05_P3.00mm_Vertical
J8: Frischwasser; JST_XH_B3B-XH-A_1x03_P2.50mm_Vertical
J9: USB Power; SolderWire-1sqmm_1x02_P5.4mm_D1.4mm_OD2.7mm
Q1, Q2, Q3, Q6, Q7: IRLML2244; SOT-23
Q4: AO3401A; SOT-23
Q5: 2N7002; SOT-23
R1, R2, R11, R13, R15, R28, R30: 100; R_0402_1005Metric
R3: 120; R_0402_1005Metric
R4, R5, R7, R9, R12, R14, R16, R17, R19, R21, R29, R31: 100k; R_0402_1005Metric
R6, R24, R25, R26, R27: 1k; R_0402_1005Metric
R8, R10, R18, R20: 22k; R_0402_1005Metric
R22, R23: 10k; R_0402_1005Metric
R32: 10m; R_Shunt_Vishay_WSK2512_6332Metric_T1.19mm
TP1: Power 3.3 Test; TestPoint_THTPad_D1.5mm_Drill0.7mm
TP2: Display Touch; TestPoint_THTPad_D1.5mm_Drill0.7mm
U1: ESP32-S3-DevKitC; ESP32-S3-DevKitC-Heemol
U2: TSR2-2450; Converter_DCDC_TRACO_TSR2-xxxx_THT
U3: LDL1117S33R; SOT-223-3_TabPin2
U4: SP3485CP; SOIC-8_3.9x4.9mm_P1.27mm
U5: PCF8523T; SOIC-8_3.9x4.9mm_P1.27mm
U6: BNO055; LGA-28_5.2x3.8mm_P0.5mm
U7: INA226; VSSOP-10_3x3mm_P0.5mm
Y1, Y2: 32.768; Crystal_SMD_3215-2Pin_3.2x1.5mm

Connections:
+3.3V: C4.1, C5.1, C8.1, J3.1, J5.1, J6.1, R6.2, R23.1, TP1.1, U3.2 (VO), U4.8 (VCC), U6.3 (VDD), U6.28 (VDDIO), U7.6 (VS)
+5V: C2.1, C3.1, Q4.2 (S), R21.1, U1.21 (5V), U2.3 (Vout), U3.3 (VI)
+12V: C1.1, D3.1 (K), D4.1 (K), D5.1 (K), D6.1 (K), D7.1 (K), J1.1, J2.2, J8.1, R19.1, U2.1 (Vin), U7.8 (Vbus)
/12V - AUS: D4.2 (A), J7.6, Q2.3 (D)
/12V - EIN: D3.2 (A), J7.7, Q1.3 (D)
/12V - Kontrolle: J7.8, R9.1
/I2C SCL: J3.4, J5.4, U1.8 (GPIO15/ADC2_CH4/32K_P), U5.6 (SCL), U6.19 (COM1), U7.5 (SCL)
/I2C SDA: J3.3, J5.3, U1.9 (GPIO16/ADC2_CH5/32K_N), U5.5 (SDA), U6.20 (COM0), U7.4 (SDA)
/Licht: D7.2 (A), J7.3, Q7.3 (D)
/Multimedia: D5.2 (A), J7.5, Q3.3 (D)
/Netz: J7.9, R7.1
/Pumpe: D6.2 (A), J7.4, Q6.3 (D)
/SB: J7.2, R17.1
/WB: J7.1, R32.4
GND: BT1.2 (-), C1.2, C2.2, C3.2, C4.2, C5.2, C6.1, C7.2, C8.2, C9.1, C10.2, C11.1, C12.2, C13.2, C14.1, D1.2 (A), D2.2 (A), H1.1, H2.1, H3.1, H4.1, J1.3, J3.2, J5.2, J6.4, J7.10, J8.3, J9.1, Q1.2 (S), Q2.2 (S), Q3.2 (S), Q5.3 (D), Q6.2 (S), Q7.2 (S), R4.2, R5.2, R8.2, R10.2, R12.1, R14.1, R16.1, R18.2, R20.2, R29.1, R31.1, U1.22 (GND), U1.23 (GND), U1.24 (GND), U1.44 (GND), U2.2 (GND), U3.1 (GND), U4.5 (GND), U5.4 (VSS), U6.2 (GND), U6.5 (PS1), U6.6 (PS0), U6.17 (COM3), U6.18 (COM2), U6.25 (GNDIO), U7.1 (A1), U7.2 (A0), U7.7 (GND)
unnamed: BT1.1 (+), U5.3 (VBAT)
unnamed: D1.1 (K), J1.2, R5.1, U1.40 (GPIO2/ADC1_CH1)
unnamed: D2.1 (K), J8.2, R4.1, U1.41 (GPIO1/ADC1_CH0)
unnamed: J2.1, R32.1
unnamed: J4.1, R3.1, U4.6 (A)
unnamed: J4.2, R3.2, U4.7 (B)
unnamed: J6.2, U1.30 (GPIO45)
unnamed: J6.3, U1.28 (GPIO47)
unnamed: J9.2, Q4.3 (D)
unnamed: Q1.1 (G), R11.2, R12.2
unnamed: Q2.1 (G), R13.2, R14.2
unnamed: Q3.1 (G), R15.2, R16.2
unnamed: Q4.1 (G), Q5.2 (S), R21.2
unnamed: Q5.1 (G), R22.1
unnamed: Q6.1 (G), R28.2, R29.2
unnamed: Q7.1 (G), R30.2, R31.2
unnamed: R9.2, R10.1, R26.2
unnamed: R17.2, R18.1, R25.2
unnamed: R19.2, R20.1, R24.1
unnamed: R7.2, R8.1, R27.2
unnamed: C9.2, R25.1, U1.4 (GPIO4/ADC1_CH3)
unnamed: C12.1, R24.2, U1.5 (GPIO5/ADC1_CH4)
unnamed: TP2.1, U1.6 (GPIO6/ADC1_CH5)
unnamed: R22.2, U1.7 (GPIO7/ADC1_CH6)
unnamed: R2.1, U1.12 (GPIO8/ADC1_CH7)
unnamed: R1.1, U1.15 (GPIO9/ADC1_CH8)
unnamed: U1.16 (GPIO10/ADC1_CH9), U4.1 (RO)
unnamed: R11.1, U1.17 (GPIO11/ADC2_CH0)
unnamed: R13.1, U1.18 (GPIO12/ADC2_CH1)
unnamed: R15.1, U1.19 (GPIO13/ADC2_CH2)
unnamed: C11.2, R26.1, U1.20 (GPIO14/ADC2_CH3)
unnamed: R30.1, U1.10 (GPIO17/ADC2_CH6)
unnamed: R28.1, U1.11 (GPIO18/ADC2_CH7)
unnamed: C10.1, R27.1, U1.27 (GPIO21)
unnamed: R2.2, U4.2 (~RE), U4.3 (DE)
unnamed: R1.2, U4.4 (DI)
unnamed: U5.1 (OSCI), Y1.2
unnamed: U5.2 (OSCO), Y1.1
unnamed: C6.2, R6.1, U5.8 (VDD)
unnamed: C7.1, U6.9 (CAP)
unnamed: C13.1, U6.27 (XIN32), Y2.2
unnamed: C14.2, U6.26 (XOUT32), Y2.1
unnamed: R23.2, U6.4 (~BOOT_LOAD_PIN), U6.11 (~RESET)
unnamed: R32.3, U7.10 (Vin+)
unnamed: R32.2, U7.9 (Vin-)

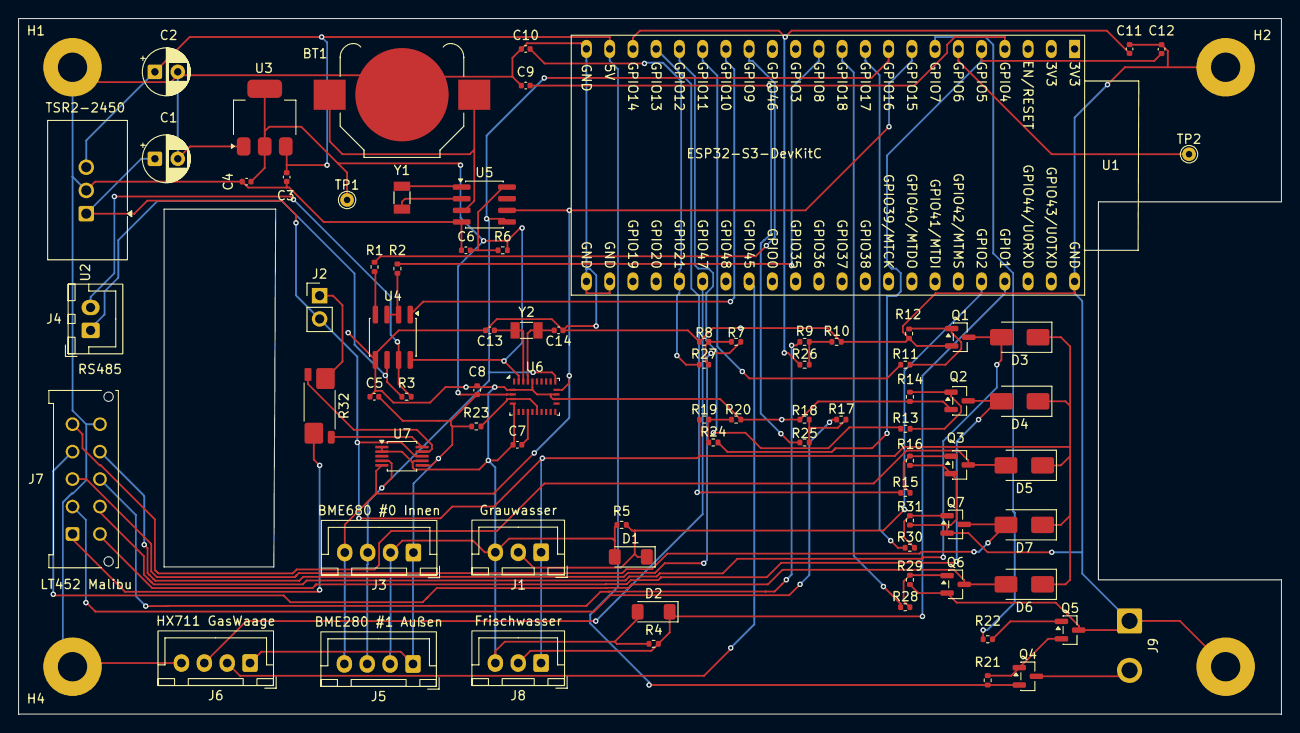
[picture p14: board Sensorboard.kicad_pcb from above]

Board: 2 copper layers, 138.0 x 76.0 mm, 85 parts (0 on the bottom side), 60 nets.

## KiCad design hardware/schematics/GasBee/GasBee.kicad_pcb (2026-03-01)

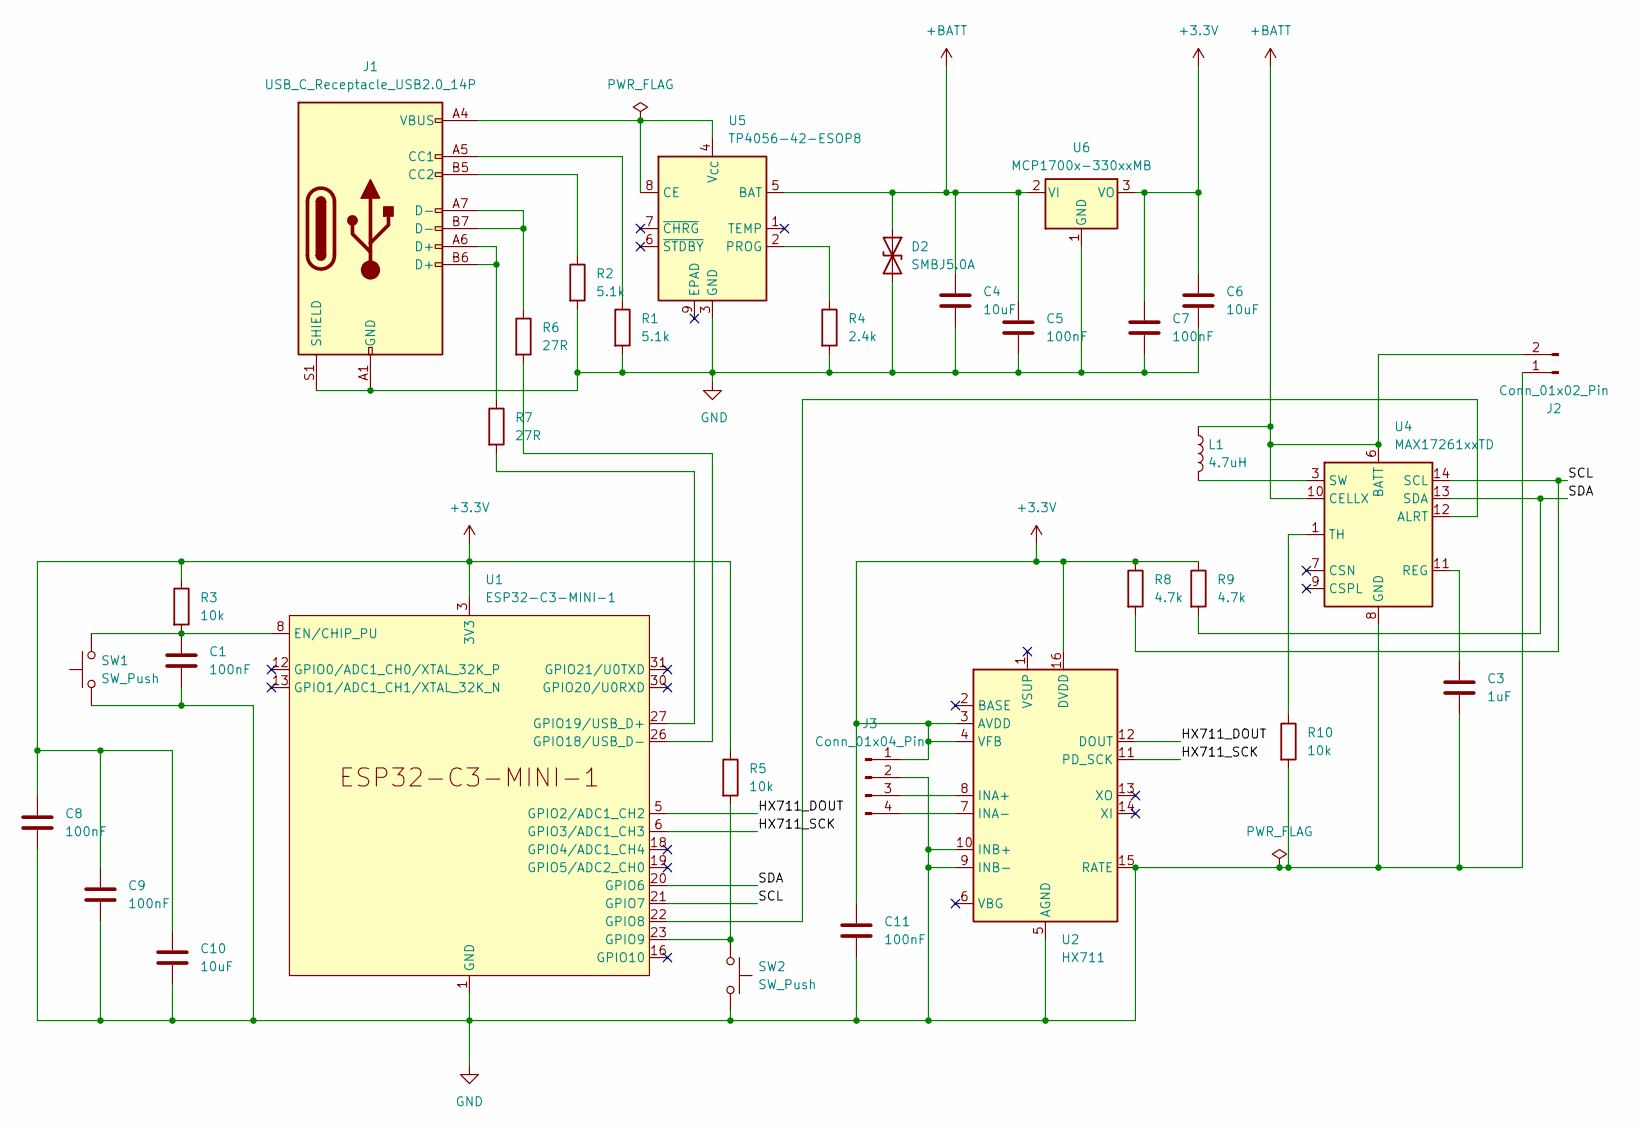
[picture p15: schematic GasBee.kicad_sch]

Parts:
C1, C5, C7, C8, C9, C11: 100nF; C_0402_1005Metric
C3: 1uF; C_0402_1005Metric
C4, C6, C10: 10uF; C_0805_2012Metric
D2: SMBJ5.0A; D_SOD-323
J1: USB_C_Receptacle_USB2.0_14P; USB_C_Receptacle_HRO_TYPE-C-31-M-12
J2: Conn_01x02_Pin; JST_PH_B2B-PH-K_1x02_P2.00mm_Vertical
J3: Conn_01x04_Pin; JST_XH_B4B-XH-A_1x04_P2.50mm_Vertical
L1: 4.7uH; L_0805_2012Metric
R1, R2: 5.1k; R_0402_1005Metric
R3, R5, R10: 10k; R_0402_1005Metric
R4: 2.4k; R_0402_1005Metric
R6, R7: 27R; R_0402_1005Metric
R8, R9: 4.7k; R_0402_1005Metric
SW1, SW2: SW_Push; SW_Push_1TS009xxxx-xxxx-xxxx_6x6x5mm
U1: ESP32-C3-MINI-1
U2: HX711; SOIC-16_3.9x9.9mm_P1.27mm
U4: MAX17261xxTD; TDFN-14-1EP_3x3mm_P0.4mm_EP1.78x2.35mm
U5: TP4056-42-ESOP8; SOIC-8-1EP_3.9x4.9mm_P1.27mm_EP2.41x3.3mm
U6: MCP1700x-330xxMB; SOT-23

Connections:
+3.3V: C6.1, C7.1, C8.1, C9.1, C10.1, C11.1, J3.1, R3.1, R5.1, R8.1, R9.1, U1.3 (3V3), U2.3 (AVDD), U2.4 (VFB), U2.16 (DVDD), U6.3 (VO)
+BATT: C4.1, C5.1, D2.1 (A1), J2.2, L1.1, U4.6 (BATT), U4.10 (CELLX), U5.5 (BAT), U6.2 (VI)
/HX711_DOUT: U1.5 (GPIO2/ADC1_CH2), U2.12 (DOUT)
/HX711_SCK: U1.6 (GPIO3/ADC1_CH3), U2.11 (PD_SCK)
/SCL: R8.2, U1.21 (GPIO7), U4.14 (SCL)
/SDA: R9.2, U1.20 (GPIO6), U4.13 (SDA)
GND: C1.2, C3.2, C4.2, C5.2, C6.2, C7.2, C8.2, C9.2, C10.2, C11.2, D2.2 (A2), J1.A1 (GND), J1.A12 (GND), J1.B1 (GND), J1.B12 (GND), J1.S1 (SHIELD), J2.1, J3.2, R1.2, R2.2, R4.2, R10.2, SW1.1, SW2.2, U1.1 (GND), U1.2 (GND), U1.11 (GND), U1.14 (GND), U1.36 (GND), U1.37 (GND), U1.38 (GND), U1.39 (GND), U1.40 (GND), U1.41 (GND), U1.42 (GND), U1.43 (GND), U1.44 (GND), U1.45 (GND), U1.46 (GND), U1.47 (GND), U1.48 (GND), U1.49 (GND), U1.50 (GND), U1.51 (GND), U1.52 (GND), U1.53 (GND), U2.5 (AGND), U2.9 (INB-), U2.10 (INB+), U2.15 (RATE), U4.8 (GND), U4.15 (GND), U5.3 (GND), U6.1 (GND)
unnamed: J1.A5 (CC1), R1.1
unnamed: J1.B5 (CC2), R2.1
unnamed: J1.A6 (D+), J1.B6 (D+), R7.1
unnamed: J1.A7 (D-), J1.B7 (D-), R6.1
unnamed: J3.3, U2.8 (INA+)
unnamed: J3.4, U2.7 (INA-)
unnamed: C1.1, R3.2, SW1.2, U1.8 (EN/CHIP_PU)
unnamed: U1.22 (GPIO8), U4.12 (ALRT)
unnamed: R5.2, SW2.1, U1.23 (GPIO9)
unnamed: R6.2, U1.26 (GPIO18/USB_D-)
unnamed: R7.2, U1.27 (GPIO19/USB_D+)
unnamed: C3.1, U4.11 (REG)
unnamed: L1.2, U4.3 (SW)
unnamed: R10.1, U4.1 (TH)
unnamed: J1.A4 (VBUS), J1.A9 (VBUS), J1.B4 (VBUS), J1.B9 (VBUS), U5.4 (V_{CC}), U5.8 (CE)
unnamed: R4.1, U5.2 (PROG)

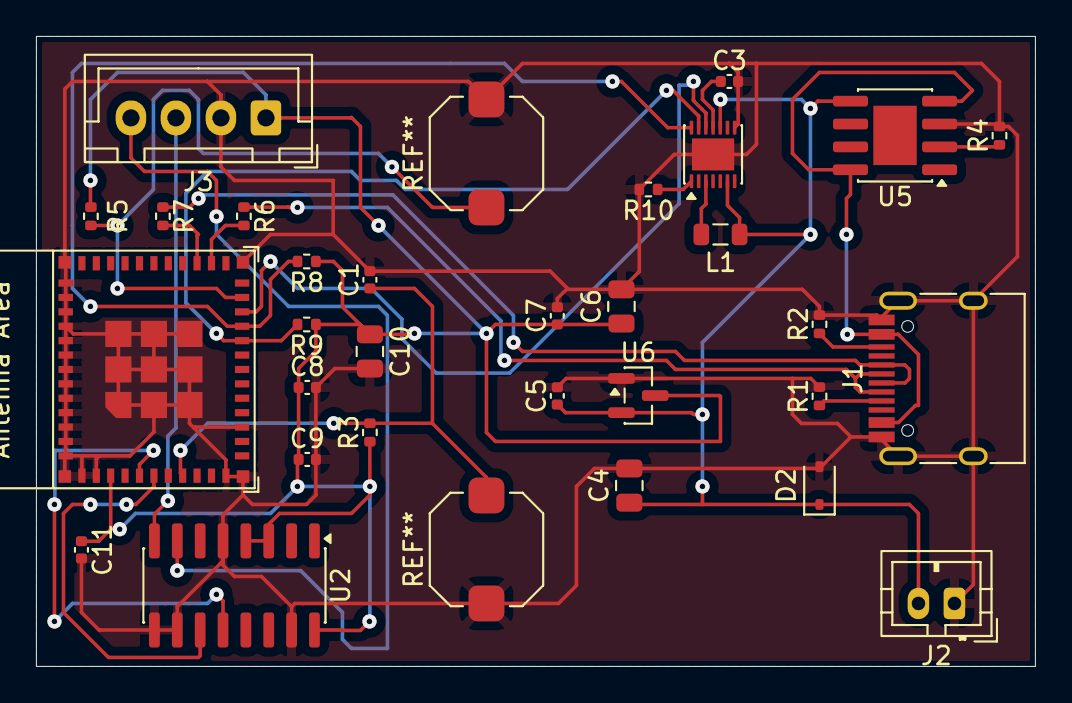
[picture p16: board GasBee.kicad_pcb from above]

Board: 2 copper layers, 55.5 x 35.0 mm, 32 parts (0 on the bottom side), 23 nets.

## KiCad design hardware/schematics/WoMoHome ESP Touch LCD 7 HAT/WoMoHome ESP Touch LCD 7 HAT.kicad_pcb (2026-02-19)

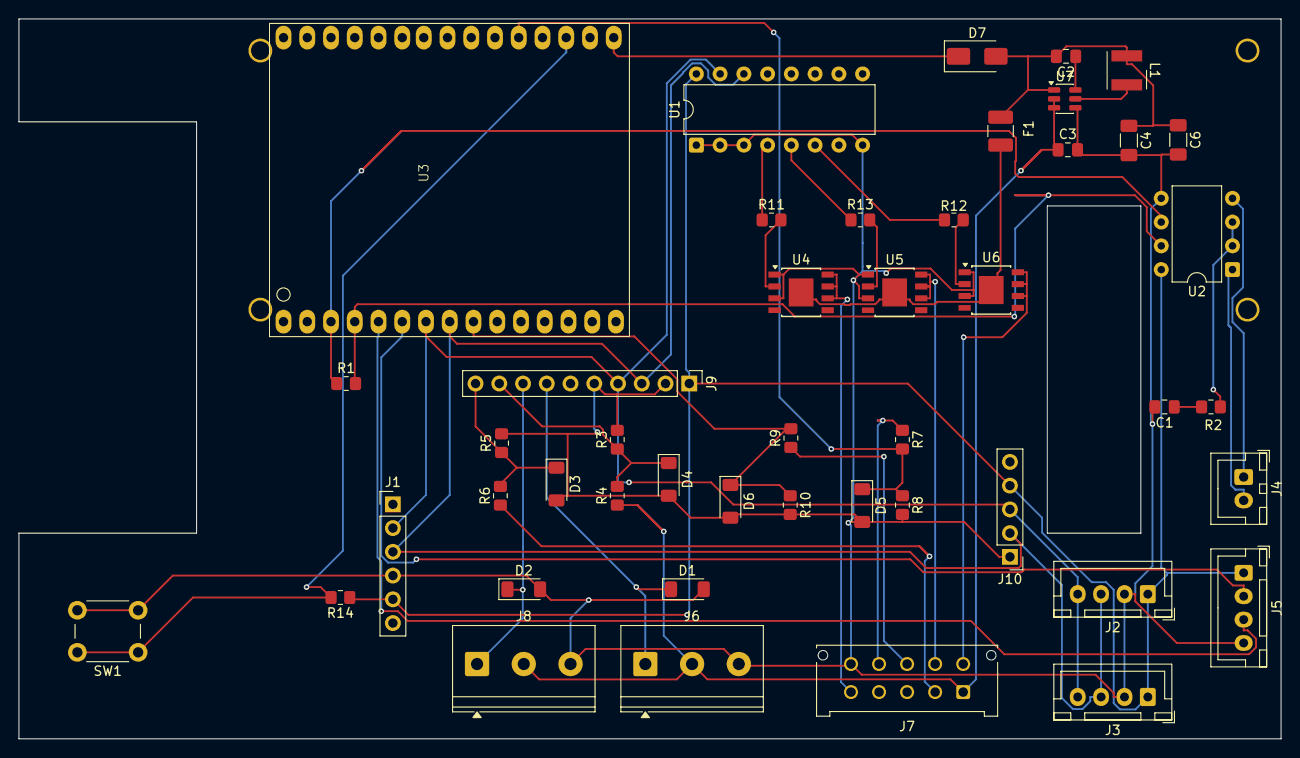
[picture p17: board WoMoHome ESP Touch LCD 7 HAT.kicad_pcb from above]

Board: 2 copper layers, 135.0 x 77.0 mm, 46 parts (0 on the bottom side), 37 nets.

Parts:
C1, C3: 10 nF; C_0805_2012Metric_Pad1.18x1.45mm_HandSolder
C2: 100nF; C_0805_2012Metric_Pad1.18x1.45mm_HandSolder
C4, C6: 22µF; C_1206_3216Metric_Pad1.33x1.80mm_HandSolder
D1, D2, D3, D4, D5, D6: BZV55B3V3; D_MiniMELF
D7: SS34; D_SMA
F1: 12V 2A; Fuse_1210_3225Metric_Pad1.42x2.65mm_HandSolder
J1: BNO055 IMU; PinHeader_1x06_P2.54mm_Vertical
J2: BME680 #1 Außen; JST_XH_B4B-XH-A_1x04_P2.50mm_Vertical
J3: BME680 #0 Innen; JST_XH_B4B-XH-A_1x04_P2.50mm_Vertical
J4: RS485; JST_XH_B2B-XH-A_1x02_P2.50mm_Vertical
J5: HX711 GasWaage; JST_XH_B4B-XH-A_1x04_P2.50mm_Vertical
J6: Sensor Grauwasser; TerminalBlock_Phoenix_PT-1,5-3-5.0-H_1x03_P5.00mm_Horizontal
J7: LT452 Malibu; Molex_Micro-Fit_3.0_43045-1012_2x05_P3.00mm_Vertical
J8: Sensor Frischwasser; TerminalBlock_Phoenix_PT-1,5-3-5.0-H_1x03_P5.00mm_Horizontal
J9: ADS1115_Module (ADC); PinHeader_1x10_P2.54mm_Vertical
J10: PCF8523 RTC; PinHeader_1x05_P2.54mm_Vertical
L1: 3.9 µH; L_Wurth_WE-LQSH-4020
R1, R11, R12, R13: 1k; R_0805_2012Metric_Pad1.20x1.40mm_HandSolder
R2, R14: 10k; R_0805_2012Metric_Pad1.20x1.40mm_HandSolder
R3, R5, R8, R10: 22k; R_0805_2012Metric_Pad1.20x1.40mm_HandSolder
R4, R6, R7, R9: 100k; R_0805_2012Metric_Pad1.20x1.40mm_HandSolder
SW1: Reset; SW_PUSH_6mm
U1: PCF8574AP; DIP-16_W7.62mm
U2: SP3485CP; DIP-8_W7.62mm
U3: SIM7600 ESP32; SIM7600X-ESP32
U4, U5, U6: BTS40K2-1EJC; Infineon_PG-DSO-8-43
U7: AP63203WU; TSOT-23-6

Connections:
+3.3V: J1.5, J2.1, J3.1, J5.1, J9.1, J10.4, R14.1, U1.16 (VDD), U2.8 (VCC)
/5 V: C2.2, C4.1, C6.1, D7.2 (A), F1.1, L1.1, U7.1 (FB)
/5 V Fuse: F1.2, U4.9 (VS), U5.9 (VS), U6.9 (VS)
/12 V - AUS: J7.6, U6.6 (OUT), U6.7 (OUT), U6.8 (OUT)
/12 V - EIN: J7.7, U5.6 (OUT), U5.7 (OUT), U5.8 (OUT)
/12V-Kontrolle: J7.8, R9.1
/Multimedia: J7.5, U4.6 (OUT), U4.7 (OUT), U4.8 (OUT)
/Netz: J7.9, R7.1
/SB: J7.2, R6.1
/SCL: J1.3, J2.3, J3.3, J9.3, J10.2, U1.14 (SCL), U3.8 (IO27)
/SDA: J1.2, J2.4, J3.4, J9.4, J10.3, U1.15 (SDA), U3.7 (IO26)
/SFW: D2.1 (K), J8.1, J9.8
/SGW: D1.1 (K), J6.1, J9.7
/WB +: C3.1, J6.2, J7.1, J8.2, R4.1, U7.2 (EN), U7.3 (IN)
GND: C1.2, C3.2, C4.2, C6.2, D1.2 (A), D2.2 (A), D3.2 (A), D4.2 (A), D5.2 (A), D6.2 (A), J1.4, J2.2, J3.2, J5.4, J6.3, J7.10, J8.3, J9.2, J9.5, J10.1, R3.2, R5.2, R8.2, R10.2, SW1.2, U1.1 (A0), U1.2 (A1), U1.3 (A2), U1.8 (GND), U2.5 (GND), U4.1 (GND), U4.3 (DEN), U5.1 (GND), U5.3 (DEN), U6.1 (GND), U6.3 (DEN), U7.4 (GND)
unnamed: C1.1, R2.2
unnamed: D3.1 (K), J9.10, R5.1, R6.2
unnamed: D4.1 (K), J9.9, R3.1, R4.2
unnamed: D5.1 (K), R7.2, R8.1, U3.20 (S_VN/39)
unnamed: D6.1 (K), R9.2, R10.1, U3.9 (IO4)
unnamed: D7.1 (K), U3.16 (VBUS)
unnamed: J4.1, U2.4 (DI)
unnamed: J4.2, U2.1 (RO)
unnamed: J5.2, U3.6 (IO25)
unnamed: J5.3, U3.5 (IO34)
unnamed: R11.1, U1.4 (P0)
unnamed: R13.1, U1.5 (P1)
unnamed: R12.2, U1.6 (P2)
unnamed: R1.1, U2.6 (A), U3.3 (IO32)
unnamed: R1.2, U2.7 (B), U3.4 (IO33)
unnamed: R2.1, U2.2 (~RE), U2.3 (DE)
unnamed: R14.2, SW1.1, U3.18 (RST/EN)
unnamed: R11.2, U4.2 (IN)
unnamed: R13.2, U5.2 (IN)
unnamed: R12.1, U6.2 (IN)
unnamed: C2.1, U7.6 (BST)
unnamed: L1.2, U7.5 (SW)

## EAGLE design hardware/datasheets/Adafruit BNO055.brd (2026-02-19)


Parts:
C1, C2: 22pF; 0805-NO
C3: 0.1uF; 0805-NO
C4: 0.1uF; 0805_10MGAP
C5: 10uF; 0805-NO
C6: 10uF; 0805_10MGAP
D1: 1n4148; SOD-323
FID1, FID2: FIDUCIAL""; FIDUCIAL_1MM
JP1: HEADER-1X676MIL; 1X06_ROUND_76
JP2: HEADER-1X476MIL; 1X04_ROUND_76
Q1, Q2: BSS138; SOT23-WIDE
R3, R4, R5, R6, R7, R10: 10K; 0805-NO
R8, R9: 10K; _0805MP
U1: MIC5225-3.3; SOT23-5
U$2: BNO055
U$29, U$30, U$31, U$32: MOUNTINGHOLE2.5_THICK; MOUNTINGHOLE_2.5_PLATED_THICK
Y1: 32.768kHz; CRYSTAL_8X3.8

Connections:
3.3V: C4.2, C6.1, JP1.2, Q1.1 (G), Q2.1 (G), R6.2, R7.2, R10.2, U1.5 (OUT), U$2.3 (VDD), U$2.4 (NBOOT_LOAD_PIN), U$2.28 (VDDIO)
5.0V: C5.1, JP1.1, R8.2, R9.2, U1.1 (IN), U1.3 (EN)
GND: C1.1, C2.1, C3.1, C4.1, C5.2, C6.2, JP1.3, R3.2, R4.2, R5.2, U1.2 (GND), U$2.2 (GND), U$2.10 (PIN10(GND)), U$2.15 (PIN15(GND)), U$2.16 (PIN16(GND)), U$2.18 (COM2(GND)), U$2.25 (GND)
I2CADDR_3V: JP2.4, R5.1, U$2.17 (COM3/I2C_ADDR)
INT_3V: JP2.3, U$2.14 (INT)
unnamed: C1.2, U$2.27 (XIN32), Y1.P$4 (2)
unnamed: C2.2, U$2.26 (XOUT32), Y1.P$1 (1)
unnamed: C3.2, U$2.9 (CAP)
NRESET_3V: D1.A, R10.1, U$2.11 (NRESET)
PS0_3V: JP2.1, R3.1, U$2.6 (PS0)
PS1_3V: JP2.2, R4.1, U$2.5 (PS1)
RST_5V: D1.C, JP1.6
SCL_3V: Q2.2 (S), R7.1, U$2.19 (COM1/SCL/RX)
SCL_5V: JP1.5, Q2.3 (D), R9.1
SDA_3V: Q1.2 (S), R6.1, U$2.20 (COM0/SDA/TX)
SDA_5V: JP1.4, Q1.3 (D), R8.1



Board: 2 copper layers, 26.7 x 20.3 mm, 31 parts (2 on the bottom side), 16 nets.

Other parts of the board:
U$3: PCBFEAT-REV-040
U$28: ADAFRUIT_TEXT_20MM
U$33: ADAFRUIT_2.5MM

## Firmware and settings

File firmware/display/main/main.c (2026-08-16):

/*
 * SPDX-FileCopyrightText: 2025-2026 Hajo Harms
 *
 * SPDX-License-Identifier: MIT
 */

#include "hardware/waveshare_rgb_lcd_port.h"
#include "lvgl.h"
#include "time/womo_time.h"
#include "freertos/FreeRTOS.h"
#include "freertos/task.h"
#include "gui/womo_theme.h"
#include "gui/womo_locale.h"
#include "gui/womo_gas_bottle.h"
#include "gui/womo_weather.h"
#include "gui/womo_battery.h"
#include "gui/womo_connectivity_modal.h"
#include "gui/womo_router_leds_modal.h"
#include "gui/womo_settings_modal.h"
#include "gui/womo_forecast_modal.h"
#include "gui/womo_tank.h"
#include "gui/womo_fonts_german.h"
#include "network/womo_wifi.h"
#include "network/womo_weather_http.h"
#include "network/womo_meteoalarm.h"
#include "network/womo_geocode.h"
#include "network/womo_router_uci.h"
#include "network/womo_http_mutex.h"
#include "network/womo_buzzer_http.h"
#include "storage/womo_sd.h"
#include "sensorboard/womo_sensorboard.h"
#include "hardware/buzzer.h"
#include "nvs.h"
#include "sdkconfig.h"
#include <inttypes.h>
#include <stdio.h>
#include <errno.h>
#include <sys/stat.h>
#include <dirent.h>
#include <string.h>
#include <time.h>
#include <math.h>
#include <limits.h>
#include <stdbool.h>
#include "esp_heap_caps.h"
#include "esp_log.h"
#include "esp_timer.h"
#include "display_config.h"

static const char *TAG = "womo_main";

static const char *PLACEHOLDER_PRESSURE = "---- hPa";
static const char *PLACEHOLDER_IAQ = "IAQ --";
static const char *PLACEHOLDER_CO2 = "CO2 ---- ppm";
static const char *PLACEHOLDER_BVOC = "bVOC --.- ppm";
static const char *PLACEHOLDER_HUMIDITY = "--.-- %";
static const char *PLACEHOLDER_TEMPERATURE = "--.- °C";
static const char *PLACEHOLDER_GPS = "GPS : ---";
#define GEOCODE_MIN_INTERVAL_US       (60LL * 1000000LL) // 60s nach Erfolg
#define GEOCODE_RETRY_INTERVAL_US      (10LL * 1000000LL) // 10s nach Fehler (TLS-Kollision)
// Boot-Delay entfernt – HTTPS-Mutex (womo_http_mutex) serialisiert TLS-Sessions
#define GEOCODE_MIN_DELTA_DEG   0.01
#define QUIET_HOUR_START 22
#define QUIET_HOUR_END   8
#define QUIET_TOUCH_TIMEOUT_MS (5 * 60 * 1000)

#include "gui/womo_thresholds.h"
/* lodepng nicht mehr benötigt – Screenshot schreibt BMP ohne Zwischenpuffer */

// Default thresholds werden jetzt über womo_thresholds.h verwaltet (veränderbar via Einstellungen)

// WiFi credentials from Kconfig
#define WIFI_SSID      CONFIG_WOMO_WIFI_SSID
#define WIFI_PASSWORD  CONFIG_WOMO_WIFI_PASSWORD
#define WIFI_MAX_RETRY CONFIG_WOMO_WIFI_MAX_RETRY

// Global LVGL objects
static lv_obj_t *title_label = NULL;
static lv_obj_t *time_label = NULL;
static lv_obj_t *date_label = NULL;
static lv_obj_t *status_btn = NULL;
static lv_obj_t *status_label = NULL;
static char status_label_last_text[80] = "";
static lv_obj_t *status_inlay = NULL;
static lv_obj_t *wifi_label = NULL;
static lv_obj_t *wifi_inner_border = NULL;
static lv_obj_t *wifi_icon_img = NULL;
static lv_obj_t *lte_icon_img = NULL;
static lv_obj_t *wifi_ap_section = NULL;  // Grüner AP-Bereich in der Mitte des WiFi/LTE-Pills
// wifi_0_bar..wifi_4_bar + cellular_0_bar..cellular_4_bar
static uint8_t       *wifi_icon_bufs[6]  = {0};  // wifi_1..wifi_6
static lv_image_dsc_t wifi_icon_dscs[6]  = {0};
static uint8_t       *lte_icon_bufs[6]   = {0};  // signal_1..signal_6
static lv_image_dsc_t lte_icon_dscs[6]   = {0};
static lv_obj_t *backlight_btn = NULL;
static lv_obj_t *backlight_icon_label = NULL;  // Material-Font-Icon für Helligkeit
static lv_obj_t *settings_btn  = NULL;  // Zahnrad-Taste → Einstellungs-Modal
static lv_obj_t *settings_icon_label = NULL;  // Material-Font-Icon für Einstellungen
static lv_obj_t *classic_btn = NULL;
static lv_obj_t *classic_label = NULL;  // Material-Font-Icon für 12V
static lv_obj_t *radio_btn = NULL;
static lv_obj_t *radio_label = NULL;    // Material-Font-Icon für Multimedia
static lv_obj_t *shore_label = NULL;
static lv_obj_t *shore_caption_label = NULL;
static lv_obj_t *shore_icon_label = NULL;  // Bolt-Icon auf Landstrom-Anzeige
static lv_obj_t *battery_board_label = NULL;
static lv_obj_t *battery_kfz_label = NULL;
static lv_obj_t *elec_vi_label    = NULL;
static lv_obj_t *elec_container   = NULL;
static lv_obj_t *fresh_water_caption_label = NULL;
static lv_obj_t *grey_water_caption_label = NULL;
static lv_obj_t *location_label = NULL;
static char location_last_text[128] = "";
static lv_obj_t *temp_label = NULL;   // Temperature display
static lv_obj_t *humid_label = NULL;  // Humidity display
static lv_obj_t *press_label = NULL;  // Pressure display (outdoor)
static lv_obj_t *press_icon_label = NULL;  // Pressure trend icon (outdoor)
static lv_obj_t *press_container = NULL;   // Row container for icon + value
static lv_obj_t *temp_label_in = NULL;   // Indoor temperature display
static lv_obj_t *humid_label_in = NULL;  // Indoor humidity display
static lv_obj_t *press_label_in = NULL;  // Indoor CO2 display (eCO2)
static lv_obj_t *gas_label_in = NULL;    // Indoor IAQ display
static lv_obj_t *voc_label_in = NULL;    // Indoor bVOC display
static lv_obj_t *air_title_label_in = NULL; // Air value heading indoor
static lv_obj_t *air_title_label = NULL; // Air value heading
static bool s_indoor_simple_view = false; // true = nur Temp+Feuchte Innen
static lv_obj_t *imu_pitch_label = NULL;
static lv_obj_t *imu_roll_label = NULL;
static lv_obj_t *imu_heading_label = NULL;
static lv_obj_t *gps_button = NULL;  // Runder Icon-Button für GPS-Details
static lv_obj_t *gps_label = NULL;    // GPS position (Alias auf gps_button)
static lv_obj_t *gps_icon_label = NULL;  // Material-Font-Icon für GPS
static char last_gps_text[256] = ""; // Zuletzt berechneter GPS-Text (Detailansicht)
static bool gps_details_visible = false;
static lv_timer_t *gps_hide_timer = NULL;
static lv_obj_t *gps_popup_panel = NULL;      // Separates Detail-Panel neben GPS-Button
static lv_obj_t *gps_popup_text_label = NULL; // Text-Label im GPS-Popup-Panel
static lv_timer_t *backlight_quiet_timer = NULL;
static bool quiet_hours_active = false;
static lv_obj_t *bg_img = NULL;       // Background image widget
static int bg_last_day_state = -1;   // -1 unknown, 0 night, 1 day (aktuell angezeigt)
static lv_obj_t *logo_img = NULL;    // Fahrzeug-Logo über Hintergrundbild
static uint8_t *logo_png_data = NULL; // Geladener Logo-PNG-Puffer
static TaskHandle_t sd_init_task_handle = NULL;
static TaskHandle_t rs485_init_task_handle = NULL;
static lv_obj_t *sensor_debug_label = NULL; // RS485 debug status
static lv_obj_t *imu_zero_modal = NULL;     // IMU calibration modal
static womo_weather_t *weather_widget = NULL; // Weather widget
static womo_battery_t *main_battery = NULL;   // Battery 1 widget
static womo_battery_t *secondary_battery = NULL; // Battery 2 widget
/* Meteoalarm ─────────────────────────────────────────────────────── */
static bool  meteoalarm_started = false;        // Task einmalig gestartet
static bool  weather_started   = false;         // Task einmalig gestartet
static lv_obj_t *meteoalarm_popup = NULL;       // aktuelles Warnungs-Popup (NULL = geschlossen)
static lv_timer_t *ui_update_timer = NULL; // Periodic UI/IMU refresh timer
static int64_t last_time_sync_try_us = 0; // Throttle multi-source time sync attempts
static const uint32_t UI_UPDATE_INTERVAL_DEFAULT_MS = 500;
static bool geocode_in_progress = false;
static bool geocode_last_failed  = false; // steuert Retry- vs. Normal-Intervall
static bool perf_monitor_visible = true;
static bool elec_visible = true;
static int64_t geocode_last_request_us = 0;
static double geocode_last_lat = NAN;
static double geocode_last_lon = NAN;
static bool backlight_on = true;
static bool classic_on = false;
static bool radio_on = false;
static bool shore_power_present = false;
static int64_t s_pwr_cmd_sent_us = 0;     // Grace-Period nach 12V-Befehl
static int64_t s_radio_cmd_sent_us = 0;   // Grace-Period nach Radio-Befehl
#define CTRL_GRACE_PERIOD_US  5000000      // 5 s: ctrl-Daten nicht überschreiben
static TaskHandle_t wifi_autoretry_handle = NULL; // Periodischer Reconnect-Versuch

typedef struct {
    bool valid;
    bool registered;
    char operator_name[32];
    float rsrp_dbm;
    uint8_t signal_percent;
} womo_lte_status_t;

static womo_lte_status_t lte_status = {0};

// Router UCI Status (wird per router_poll_task aktualisiert)
static womo_router_wifi_status_t  s_router_wifi = {0};
static womo_router_lte_status_t   s_router_lte  = {0};
static womo_router_ap_status_t    s_router_ap   = {0};
static SemaphoreHandle_t          s_router_mutex = NULL;
static bool                       s_router_reachable = false;
static TaskHandle_t              s_router_poll_handle = NULL;
#define ROUTER_POLL_INTERVAL_MS  15000

// Gas bottle widgets
static womo_gas_bottle_t *gas_bottle_a = NULL; // Gas bottle A (HX711 channel A)
static womo_gas_bottle_t *gas_bottle_b = NULL; // Gas bottle B (HX711 channel B)
static lv_obj_t *gas_label_front = NULL; // Label "Vorne" unter Flasche A
static lv_obj_t *gas_label_rear = NULL;  // Label "Hinten" unter Flasche B
static lv_obj_t *gas_info_label = NULL;  // Aktive Flasche + Restzeit/Verbrauch
static lv_obj_t *gas_replace_modal = NULL; // Dialog für Flaschenwechsel
static bool gas_nc_active = false; // true, wenn HX711 als nicht angeschlossen gemeldet wurde

// Water tank widgets
static womo_tank_t *fresh_water_tank = NULL;
static womo_tank_t *grey_water_tank = NULL;
static lv_obj_t *tank_info_label = NULL;  // Tank-Verbrauch (L/h) + Restlaufzeit

// RS485 packet counter
static uint32_t rs485_packet_count = 0;

static portMUX_TYPE display_data_spinlock = portMUX_INITIALIZER_UNLOCKED;
static womo_sensor_data_t latest_sensor_data = {0};
static uint32_t latest_packet_count = 0;
static bool latest_data_valid = false;
static int64_t rs485_last_packet_time_us = 0;
static int64_t rs485_watchdog_start_us = 0;
static bool rs485_timeout_active = false;
static const int64_t RS485_TIMEOUT_US = 5LL * 60LL * 1000000LL;  // 5 Minuten in Mikrosekunden
static bool rs485_waiting_for_handshake = false;
static bool rs485_invalid_data_active = false;

typedef enum {
    SYSTEM_STATUS_SOURCE_MANUAL = 0,
    SYSTEM_STATUS_SOURCE_SENSOR,
    SYSTEM_STATUS_SOURCE_MAX
} system_status_source_t;

typedef struct {
    bool active;
    womo_status_level_t level;
    womo_string_id_t detail_id;
} system_status_entry_t;

static system_status_entry_t system_status_entries[SYSTEM_STATUS_SOURCE_MAX] = {0};
static womo_status_level_t system_status_current_level = WOMO_STATUS_OK;
static womo_string_id_t system_status_current_detail = STR_MAX;
static womo_status_level_t system_status_sensor_level = WOMO_STATUS_OK;

// --- Sensor-Fehler-Stapel: pro Quelle aktueller, gelatchter und quittierter Level ---
//
// Fehler-Management:
//   1. "current" wird jeden Tick neu evaluiert (Sensor-Schwellwert-Vergleich).
//   2. "latched" steigt mit current (sticky), fällt erst nach Quittierung +
//      stabiler Erholung (ok_streak >= SENSOR_ERR_OK_DEBOUNCE).
//   3. "acked" wird per Touch-Quittierung auf latched gesetzt.
//   4. Unquittiert = latched > acked → System-Alarm, Buzzer.
//   5. Widget-Farbe folgt "current" (Echtzeit), nicht latched/acked.
//
#define SENSOR_ERR_OK_DEBOUNCE  6   // 6 Ticks × 500 ms = 3 s stabile Erholung nötig

typedef enum {
    SENSOR_ERR_SRC_GAS = 0,
    SENSOR_ERR_SRC_FRESH,
    SENSOR_ERR_SRC_GREY,
    SENSOR_ERR_SRC_BAT,
    SENSOR_ERR_SRC_RS485,  // RS485 Timeout / Verbindungsverlust
    SENSOR_ERR_SRC_IAQ,    // Luftqualität (BME680 indoor IAQ)
    SENSOR_ERR_SRC_MAX
} sensor_err_src_t;

static const char * const sensor_err_src_name[SENSOR_ERR_SRC_MAX] = {
    "Gas", "Wasser", "Abw.", "Bat", "Sensor", "IAQ"
};

typedef struct {
    womo_status_level_t current;   // Aktuell evaluierter Level (jeden Tick neu berechnet)
    womo_status_level_t latched;   // Gelatchter Level (steigt mit current, fällt erst nach Quittierung + Erholung)
    womo_status_level_t acked;     // Per Touch quittierter Level
    uint8_t ok_streak;             // Aufeinanderfolgende Ticks mit current == OK
} sensor_err_state_t;

static sensor_err_state_t sensor_err_states[SENSOR_ERR_SRC_MAX] = {0};
static int sensor_err_display_idx = -1;
static char sensor_detail_text[32] = "";
static portMUX_TYPE system_status_spinlock = portMUX_INITIALIZER_UNLOCKED;
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
void app_main()
{
    // ── Log-Level zentral konfigurieren (siehe display_config.h) ──────────
    esp_log_level_set("womo_main",        LOG_LEVEL_MAIN);
    esp_log_level_set("WaveShare_7_UI",   LOG_LEVEL_UI);
    esp_log_level_set("lv_port",          LOG_LEVEL_LVGL_PORT);
    esp_log_level_set("womo_display",     LOG_LEVEL_DISPLAY_HW);
    esp_log_level_set("sensorboard",    LOG_LEVEL_SENSORBOARD);
    esp_log_level_set("womo_wifi",        LOG_LEVEL_WIFI);
    esp_log_level_set("esp_netif_lwip",   LOG_LEVEL_WIFI);
    esp_log_level_set("esp_netif_handlers", LOG_LEVEL_WIFI);
    esp_log_level_set("weather_http",     LOG_LEVEL_WEATHER_HTTP);
    esp_log_level_set("meteoalarm",       LOG_LEVEL_METEOALARM);
    esp_log_level_set("geocode",          LOG_LEVEL_GEOCODE);
    esp_log_level_set("router_uci",       LOG_LEVEL_ROUTER_UCI);
    esp_log_level_set("http_mutex",       LOG_LEVEL_HTTP_MUTEX);
    esp_log_level_set("womo_buzz_http",   LOG_LEVEL_BUZZER_HTTP);
    esp_log_level_set("womo_sd",          LOG_LEVEL_SD);
    esp_log_level_set("womo_time",        LOG_LEVEL_TIME);
    esp_log_level_set("womo_sun_calc",    LOG_LEVEL_SUN_CALC);
    esp_log_level_set("womo_theme",       LOG_LEVEL_THEME);
    esp_log_level_set("weather",          LOG_LEVEL_WEATHER_WIDGET);
    esp_log_level_set("battery",          LOG_LEVEL_BATTERY);
    esp_log_level_set("tank_widget",      LOG_LEVEL_TANK);
    esp_log_level_set("gas_bottle",       LOG_LEVEL_GAS);
    esp_log_level_set("thresholds",       LOG_LEVEL_THRESHOLDS);
    esp_log_level_set("womo_fonts_german",LOG_LEVEL_FONTS);
    esp_log_level_set("forecast_modal",   LOG_LEVEL_FORECAST_MODAL);
    esp_log_level_set("womo_modal",       LOG_LEVEL_CONN_MODAL);
    esp_log_level_set("settings_modal",   LOG_LEVEL_SETTINGS_MODAL);
    esp_log_level_set("ROUTER_LEDS",      LOG_LEVEL_ROUTER_LEDS);

    // Backlight sofort AUS – CH422G könnte nach Reset in undefiniertem
    // Zustand sein.  Das Backlight wird erst nach vollständiger UI-
    // Initialisierung + Theme + Hintergrundbild explizit eingeschaltet.
    wavesahre_rgb_lcd_bl_off();

    // Buzzer so früh wie möglich – braucht nur LEDC + GPIO, kein Display/WiFi
    display_buzzer_init();
    display_buzzer_startup();

    // Initialize time management
    womo_time_init();
    rs485_watchdog_start_us = esp_timer_get_time();
    rs485_last_packet_time_us = rs485_watchdog_start_us;
    rs485_timeout_active = false;
    
    // Initialize WiFi + sofort async verbinden (läuft parallel zu Display-HW + UI-Konstruktion)
    ESP_LOGI(TAG, "Initializing WiFi...");
    womo_wifi_init();
    {
        char ap_ssid[33] = {0}, ap_pass[65] = {0};
        if (womo_ap_cfg_load(ap_ssid, sizeof(ap_ssid), ap_pass, sizeof(ap_pass)) == ESP_OK
            && ap_ssid[0] != '\0') {
            ESP_LOGI(TAG, "WiFi boot: AP-Konfiguration '%s'", ap_ssid);
            womo_wifi_connect_async(ap_ssid, ap_pass, 1);
        } else {
            ESP_LOGI(TAG, "WiFi boot async (Kconfig): %s", WIFI_SSID);
            womo_wifi_connect_async(WIFI_SSID, WIFI_PASSWORD, 1);
        }
    }

#if WOMO_ENABLE_BUZZER_STUDIO_HTTP
    esp_err_t buzzer_http_err = womo_buzzer_http_start();
    if (buzzer_http_err == ESP_OK) {
        ESP_LOGI(TAG, "Buzzer-Studio HTTP aktiv: /buzzer_studio.html");
    } else {
        ESP_LOGW(TAG, "Buzzer-Studio HTTP Start fehlgeschlagen: %s", esp_err_to_name(buzzer_http_err));
    }
#else
    ESP_LOGI(TAG, "Buzzer-Studio HTTP deaktiviert (WOMO_ENABLE_BUZZER_STUDIO_HTTP=0)");
#endif

    // Initialize theme (default location: Central Europe)
    // Sonnenzeiten werden automatisch via GPS berechnet (router_poll_task)
    womo_theme_init(50.0, 10.0);  // Approximate Germany
    womo_theme_reset();  // Reset cached state (wichtig bei Power-Cycle!)
    
    // Fallback sunrise/sunset – MESZ-Durchschnitt für Zentraleuropa.
    // Wird bei erstem GPS-Fix oder nach NTP-Sync via sun_calc überschrieben.
    womo_theme_set_sun_times(6, 30, 20, 0);
    
    // Initialize display (uses I2C for touch controller)
    {
        int64_t t0 = esp_timer_get_time();
        waveshare_esp32_s3_rgb_lcd_init();
        ESP_LOGI(TAG, "Display init finished after %d ms",
                 (int)((esp_timer_get_time() - t0) / 1000));
    }

    /* Sichtbarer Sofort-Start: das RGB-Init hat die Framebuffer bereits mit
     * der Theme-Hintergrundfarbe vorgefüllt. Backlight hier schon einschalten,
     * damit lange Folge-Init-Schritte nicht wie ein totes Display wirken. */
    if (wavesahre_rgb_lcd_bl_on() == ESP_OK) {
        backlight_on = true;
        ESP_LOGI(TAG, "Backlight enabled early after display init");
    } else {
        ESP_LOGW(TAG, "Early backlight enable failed");
    }

    ESP_LOGI(TAG, "Display WoMo Home Control with Dynamic Theme");

    // ── LVGL sperren → UI aufbauen ──────────────────────────────────
    // Nach lvgl_port_init() läuft der LVGL-Task bereits.  Mutex nehmen,
    // damit kein Frame gerendert wird, bevor Theme + Widgets stehen.
    
    // Cache zurücksetzen beim Boot, damit Theme+Hintergrundbild korrekt geladen werden
    bg_last_day_state  = -1;
    bg_img             = NULL;
    
    ESP_LOGI(TAG, "Waiting for LVGL lock to build UI...");
    if (lvgl_port_lock(5000)) {
        ESP_LOGI(TAG, "LVGL lock acquired, building UI");
        lv_obj_t *screen = lv_scr_act();
        lv_obj_add_flag(screen, LV_OBJ_FLAG_CLICKABLE);
        lv_obj_clear_flag(screen, LV_OBJ_FLAG_SCROLLABLE);
        lv_obj_add_event_cb(screen, screen_event_handler, LV_EVENT_CLICKED, NULL);
        lvgl_touch_set_wake_cb(touch_wake_cb);

        // Initiales Theme: Dunkelblau (Nacht) als Fallback.
        // Besser zu dunkel als zu hell – blendet nicht und ist nachts korrekt.
        // Das echte Theme+Hintergrundbild wird nach Zeitvalidierung geladen.
        lv_obj_set_style_bg_color(screen, WOMO_COLOR_NIGHT_NORMAL, 0);
        lv_obj_set_style_bg_opa(screen, LV_OPA_COVER, 0);
        
        // Initialize locale system
        womo_locale_init();
        womo_locale_register_change_cb(on_locale_changed);
        womo_thresholds_init();
        womo_thresholds_register_change_cb(on_thresholds_changed);
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

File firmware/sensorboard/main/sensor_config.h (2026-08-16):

/*
 * SPDX-FileCopyrightText: 2025-2026 Hajo Harms
 *
 * SPDX-License-Identifier: MIT
 */

#pragma once

#include "womo_config.h"

/* WoMoHome ESP32 Sensor Board Konfiguration
 * Sensor Board Configuration (ESP32-S3 DevKitC-1, N16R8)
 * Stand: Feb 2026 — Pinbelegung gemäß DevKitC-1 Header-Block
 *
 * Pinout Übersicht ESP32-S3 WROOM-1 (DevKitC-1):
 *
 *                                             Detail J1 (links)        |           Detail J3 (rechts)
 *                            Funktion | Type | Use | Name | Pin        |       Pin | NAME | USE | Type  | Funktion
 * ------------------------------------|------|-----|------|------------------------|------|-----|-------|------------------------------------------
 *                  3.3 V power supply |    P |  🟩 |  3V3 | 1          E         1 | GND  | 🟩  | G     | Ground
 *                  3.3 V power supply |    P |  🟩 |  3V3 | 2          S         2 | TX   | 🟩  | I/O/T | U0TXD, GPIO43, CLK_OUT1
 *                               Reset |    I |  🟩 |  RST | 3          P         3 | RX   | 🟩  | I/O/T | U0RXD, GPIO44, CLK_OUT2
 *    (ADC1_CH3, RTC, GPIO4) Batt1 KFZ | I/O/T|  🟨 |    4 | 4          3         4 | 1    | 🟨  | I/O/T | Tank1 Frisch (GPIO1, RTC, ADC1_CH0)
 *  (ADC1_CH4, RTC, GPIO5) Batt2 Board | I/O/T|  🟨 |    5 | 5          2         5 | 2    | 🟨  | I/O/T | Tank2 Grau (GPIO2, RTC, ADC1_CH1)
 *         DC1_CH5, RTC, GPIO6) WAKEUP | I/O/T|  🟨 |    6 | 6          -         6 | 42   | 🟩  | I/O/T | MTMS, GPIO42
 *   (ADC1_CH6, RTC, GPIO7) Display 5V | I/O/T|  🟨 |    7 | 7          S         7 | 41   | 🟩  | I/O/T | MTDI, GPIO41
 *     (ADC2_CH4, RTC, GPIO15) I2C SCL | I/O/T|  🟨 |   15 | 8          3         8 | 40   | 🟩  | I/O/T | MTDO, GPIO40
 *     (ADC2_CH5, RTC, GPIO16) I2C SDA | I/O/T|  🟨 |   16 | 9          -         9 | 39   | 🟩  | I/O/T | MTCK, GPIO39
 * (ADC2_CH6, U1TXD, RTC, GPIO17) frei | I/O/T|  ⬜ |   17 | 10         W        10 | 38   | 🟨  | I/O/T | RGB_LED  (GPIO38)
 * (ADC2_CH7, U1RXD, RTC, GPIO18) frei | I/O/T|  ⬜ |   18 | 11         R        11 | 37   | 🟥  | I/O/T | ⚠ PSRAM (GPIO37, nicht nutzbar!)
 *               (ADC1_CH7, RTC) GPIO8 | I/O/T|  ⬜ |    8 | 12         O        12 | 36   | 🟥  | I/O/T | ⚠ PSRAM (GPIO36, nicht nutzbar!)
 *                ADC1_CH2, RTC, GPIO3 | I/O/T|  ⬜ |    3 | 13         O        13 | 35   | 🟥  | I/O/T | ⚠ PSRAM (GPIO35, nicht nutzbar!)
 *                   GPIO46, STRAP/LOG | I/O/T|  🟩 |   46 | 14         M        14 | 0    | 🟩  | I/O/T | BOOT/STRAP, GPIO0
 *               (ADC1_CH8, RTC) GPIO9 | I/O/T|  ⬜ |    9 | 15         -        15 | 45   | 🟨  | I/O/T | HX711 SCK (GPIO45)
 *              (ADC1_CH9, RTC) GPIO10 | I/O/T|  ⬜ |   10 | 16         1        16 | 48   | 🟩  | I/O/T | Onboard WS2812 RGB-LED (GPIO48)
 *     (ADC2_CH0, RTC, GPIO11) 12V EIN | I/O/T|  🟨 |   11 | 17                  17 | 47   | 🟨  | I/O/T | HX711 DOUT (GPIO47)
 *     (ADC2_CH1, RTC, GPIO12) 12V AUS | I/O/T|  🟨 |   12 | 18                  18 | 21   | 🟨  | I/O/T | AC 220V Sence (GPIO21, RTC)
 *  (ADC2_CH2, RTC, GPIO13) Multimedia | I/O/T|  🟨 |   13 | 19                  19 | 20   | 🟩  | I/O/T | USB_D+, GPIO20, RTC
 *   (ADC2_CH3, RTC, GPIO14) 12V Sence | I/O/T|  🟨 |   14 | 20                  20 | 19   | 🟩  | I/O/T | USB_D-, GPIO19, RTC
 *                    5 V power supply |    P |  🟩 |   5V | 21                  21 | GND  | 🟩  | G     | Ground
 *                              Ground |    G |  🟩 |  GND | 22                  22 | GND  | 🟩  | G     | Ground
 * ------------------------------------|------|-----|------|------------------------|------|------|-----|-------|-----------------------------------------
 *
 * Legende:
 * - Funktion: Hauptfunktion des Pins (laut Datenblatt, kann mehrfach belegt sein)
 * - Type: I=Input, O=Output, P=Power, G=Ground, T=Touch, RTC=RTC Power Domain, ADC=ADC-Kanal
 * - Use: 🟩 = Fest belegt für Hauptfunktion, 🟨 = Sensor Board, ⬜ = Frei/Nicht belegt
 */

// ====================================================================================
// Board Information
// ====================================================================================
#define SENSOR_BOARD_NAME "ESP32-S3-WROOM-1"

// ====================================================================================
// I2C-Bus für Sensoren auf Header J1 (SDA=GPIO16, SCL=GPIO15)
// ====================================================================================
#define SENSOR_I2C_EXT_PORT 0
#define SENSOR_I2C_EXT_SDA_GPIO 16
#define SENSOR_I2C_EXT_SCL_GPIO 15
#define SENSOR_I2C_EXT_SPEED_HZ 100000
#define SENSOR_I2C_EXT_PULLUP_ENABLE 1
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

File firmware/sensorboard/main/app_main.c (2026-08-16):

/*
 * SPDX-FileCopyrightText: 2023-2025 Espressif Systems (Shanghai) CO LTD
 * SPDX-FileCopyrightText: 2025-2026 Hajo Harms (modifiziert)
 *
 * SPDX-License-Identifier: Apache-2.0
 */

#include <stdio.h>
#include "freertos/FreeRTOS.h"
#include "freertos/task.h"
#include "esp_log.h"
#include "esp_system.h"
#include "nvs_flash.h"
#include "sensor_config.h"
#include "esp_wifi.h"
#include "sensors/analog_sensor.h"
#include "sensors/bno055_sensor.h"
#include "sensors/bme680_sensor.h"
#include "sensors/hx711_sensor.h"
#include "sensors/ina226_sensor.h"
#include "time/rtc_pcf8523.h"
#include "time/time_sync.h"
#include "network/espnow_modem.h"
#include "network/wifi/sensor_wifi.h"
#include "network/wifi/sensor_http.h"
#include "network/ble_manager.h"
#include "network/gasbee_ble_client.h"
#include "network/ruuvi_ble_scanner.h"
#include "hal/deep_sleep.h"
#include "led_strip.h"
#include "driver/gpio.h"
#include "driver/rtc_io.h"

static const char *TAG = "sensor_main";

/** Log-Level je Modul gemäß sensor_config.h setzen. */
static void sensor_log_init(void)
{
    esp_log_level_set("sensor_main",  LOG_LEVEL_SENSOR_MAIN);
    esp_log_level_set("deep_sleep",   LOG_LEVEL_DEEP_SLEEP);
    esp_log_level_set("womo_rs485_legacy",   LOG_LEVEL_SENSORBOARD);
    esp_log_level_set("espnow_modem",  LOG_LEVEL_SENSORBOARD);
    esp_log_level_set("analog",       LOG_LEVEL_ANALOG);
    esp_log_level_set("bno055_app",   LOG_LEVEL_BNO055);
    esp_log_level_set("BNO055",       LOG_LEVEL_BNO055);
    esp_log_level_set("bme680_app",   LOG_LEVEL_BME680);
    esp_log_level_set("bme680",       LOG_LEVEL_BME680);
    esp_log_level_set("hx711_app",    LOG_LEVEL_HX711);
    esp_log_level_set("ina226",       LOG_LEVEL_INA226);
    esp_log_level_set("ble_manager",   LOG_LEVEL_BLE_MANAGER);
    esp_log_level_set("gasbee_ble",   LOG_LEVEL_GASBEE_BLE);
    esp_log_level_set("ruuvi_ble",    LOG_LEVEL_RUUVI_BLE);
    esp_log_level_set("i2c_bus",      LOG_LEVEL_I2C_BUS);
    esp_log_level_set("pcf8523_app",  LOG_LEVEL_PCF8523);
    esp_log_level_set("time_sync",    LOG_LEVEL_TIME_SYNC);
    esp_log_level_set("wifi",         LOG_LEVEL_WIFI);
    esp_log_level_set("esp_netif_lwip", LOG_LEVEL_WIFI);
    esp_log_level_set("esp_netif_handlers", LOG_LEVEL_WIFI);
}

/** Onboard WS2812 RGB-LED (GPIO48) ausschalten. */
static void rgb_led_off(void)
{
    led_strip_config_t strip_cfg = {
        .strip_gpio_num   = SENSOR_RGB_LED_GPIO,
        .max_leds         = 1,
        .led_model        = LED_MODEL_WS2812,
        .color_component_format = LED_STRIP_COLOR_COMPONENT_FMT_GRB,
        .flags.invert_out = false,
    };
    led_strip_rmt_config_t rmt_cfg = {
        .clk_src        = RMT_CLK_SRC_DEFAULT,
        .resolution_hz  = 10 * 1000 * 1000,
        .flags.with_dma = false,
    };
    led_strip_handle_t led = NULL;
    esp_err_t err = led_strip_new_rmt_device(&strip_cfg, &rmt_cfg, &led);
    if (err == ESP_OK) {
        led_strip_clear(led);
        led_strip_refresh(led);
        vTaskDelay(pdMS_TO_TICKS(50));
        led_strip_del(led);
        ESP_LOGI(TAG, "RGB-LED (GPIO%d) ausgeschaltet", SENSOR_RGB_LED_GPIO);
    } else {
        ESP_LOGW(TAG, "RGB-LED init fehlgeschlagen: %s", esp_err_to_name(err));
    }
}

/**
 * Display 5V einschalten + 12V Bordnetz EIN-Puls.
 * Wird direkt beim Boot/Wakeup aufgerufen – VOR allem anderen.
 */
static void pwr_12v_on_early(void)
{
    /* Display 5V einschalten: GPIO7 HIGH → Q5 (2N7002) leitet → Q4 (AO3401A) leitet */
    gpio_config_t cfg = {
        .pin_bit_mask   = BIT64(SENSOR_DISPLAY_PWR_GPIO),
        .mode           = GPIO_MODE_OUTPUT,
        .pull_up_en     = GPIO_PULLUP_DISABLE,
        .pull_down_en   = GPIO_PULLDOWN_DISABLE,
        .intr_type      = GPIO_INTR_DISABLE,
    };
    gpio_config(&cfg);
    gpio_set_level(SENSOR_DISPLAY_PWR_GPIO, 1);  /* HIGH → Q5 leitet → Display EIN */
    ESP_LOGI(TAG, "Display 5V EIN (GPIO%d HIGH, Q5→Q4 leitet)", SENSOR_DISPLAY_PWR_GPIO);

    /* LBE 12V-Relais EIN: bistabiles Relais benötigt Puls 1-3 s auf GPIO11.
     * GPIO11 (EIN) und GPIO12 (AUS) müssen im Ruhezustand LOW sein! */
    gpio_config_t cfg2 = {
        .pin_bit_mask   = BIT64(SENSOR_PWR_12V_ON_GPIO) | BIT64(SENSOR_PWR_12V_OFF_GPIO),
        .mode           = GPIO_MODE_OUTPUT,
        .pull_up_en     = GPIO_PULLUP_DISABLE,
        .pull_down_en   = GPIO_PULLDOWN_DISABLE,
        .intr_type      = GPIO_INTR_DISABLE,
    };
    gpio_config(&cfg2);
    gpio_set_level(SENSOR_PWR_12V_ON_GPIO,  0);   /* sicher LOW vor Puls */
    gpio_set_level(SENSOR_PWR_12V_OFF_GPIO, 0);
    gpio_set_level(SENSOR_PWR_12V_ON_GPIO,  1);   /* EIN-Puls starten */
    vTaskDelay(pdMS_TO_TICKS(100));              /* 100 ms Puls (bistabiles Relais) */
    gpio_set_level(SENSOR_PWR_12V_ON_GPIO,  0);   /* Puls beenden → LOW */
    ESP_LOGI(TAG, "LBE 12V EIN (GPIO%d 100ms-Puls abgeschlossen)", SENSOR_PWR_12V_ON_GPIO);
}
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

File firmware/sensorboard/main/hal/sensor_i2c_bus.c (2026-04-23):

/*
 * SPDX-FileCopyrightText: 2025-2026 Hajo Harms
 *
 * SPDX-License-Identifier: MIT
 */

#include "hal/sensor_i2c_bus.h"

#include "esp_check.h"
#include "esp_log.h"
#include "freertos/FreeRTOS.h"
#include "freertos/task.h"
#include "freertos/semphr.h"
#include "driver/gpio.h"
#include <i2c_bus.h>
#include "sensor_config.h"

static const char *TAG = "i2c_bus";

static i2c_bus_handle_t s_bus = NULL;
static i2c_master_bus_handle_t s_internal = NULL;
static SemaphoreHandle_t s_bus_mutex = NULL;

/**
 * @brief I2C-Bus-Recovery: 9 SCL-Pulse als GPIO senden, um einen hängenden
 *        Slave (SDA klemmt LOW nach unterbrochenem Transfer) zu befreien.
 *        Danach STOP-Condition erzeugen.
 */
static void i2c_bus_recover(void)
{
    ESP_LOGW(TAG, "I2C Bus-Recovery: 9 SCL-Pulse auf GPIO%d", SENSOR_I2C_EXT_SCL_GPIO);

    gpio_config_t scl_cfg = {
        .pin_bit_mask = BIT64(SENSOR_I2C_EXT_SCL_GPIO),
        .mode         = GPIO_MODE_OUTPUT_OD,
        .pull_up_en   = GPIO_PULLUP_ENABLE,
        .pull_down_en = GPIO_PULLDOWN_DISABLE,
        .intr_type    = GPIO_INTR_DISABLE,
    };
    gpio_config_t sda_cfg = {
        .pin_bit_mask = BIT64(SENSOR_I2C_EXT_SDA_GPIO),
        .mode         = GPIO_MODE_INPUT_OUTPUT_OD,
        .pull_up_en   = GPIO_PULLUP_ENABLE,
        .pull_down_en = GPIO_PULLDOWN_DISABLE,
        .intr_type    = GPIO_INTR_DISABLE,
    };
    gpio_config(&scl_cfg);
    gpio_config(&sda_cfg);

    gpio_set_level(SENSOR_I2C_EXT_SDA_GPIO, 1);
    gpio_set_level(SENSOR_I2C_EXT_SCL_GPIO, 1);
    vTaskDelay(pdMS_TO_TICKS(1));

    for (int i = 0; i < 9; i++) {
        gpio_set_level(SENSOR_I2C_EXT_SCL_GPIO, 0);
        esp_rom_delay_us(5);
        gpio_set_level(SENSOR_I2C_EXT_SCL_GPIO, 1);
        esp_rom_delay_us(5);
        /* Sobald SDA wieder HIGH → Slave hat freigegeben */
        if (gpio_get_level(SENSOR_I2C_EXT_SDA_GPIO)) {
            ESP_LOGI(TAG, "SDA freigegeben nach %d Pulsen", i + 1);
            break;
        }
    }

    /* STOP-Condition: SDA LOW → SCL HIGH → SDA HIGH */
    gpio_set_level(SENSOR_I2C_EXT_SDA_GPIO, 0);
    esp_rom_delay_us(5);
    gpio_set_level(SENSOR_I2C_EXT_SCL_GPIO, 1);
    esp_rom_delay_us(5);
    gpio_set_level(SENSOR_I2C_EXT_SDA_GPIO, 1);
    esp_rom_delay_us(5);

    /* Pins wieder auf Input setzen – i2c_new_master_bus konfiguriert sie neu */
    gpio_reset_pin(SENSOR_I2C_EXT_SCL_GPIO);
    gpio_reset_pin(SENSOR_I2C_EXT_SDA_GPIO);
    vTaskDelay(pdMS_TO_TICKS(10));
}

esp_err_t i2c_bus_init(void)
{
    if (s_bus && s_internal) {
        return ESP_OK;
    }

    /* Bus-Recovery vor Init: befreit hängende Slaves (SDA klemmt LOW) */
    i2c_bus_recover();

    i2c_config_t conf = {
        .mode = I2C_MODE_MASTER,
        .sda_io_num = SENSOR_I2C_EXT_SDA_GPIO,
        .scl_io_num = SENSOR_I2C_EXT_SCL_GPIO,
        .sda_pullup_en = SENSOR_I2C_EXT_PULLUP_ENABLE,
        .scl_pullup_en = SENSOR_I2C_EXT_PULLUP_ENABLE,
        .master.clk_speed = SENSOR_I2C_EXT_SPEED_HZ,
        .clk_flags = 0,
    };

    s_bus = i2c_bus_create(SENSOR_I2C_EXT_PORT, &conf);
    ESP_RETURN_ON_FALSE(s_bus != NULL, ESP_FAIL, TAG, "i2c_bus_create failed");

    s_internal = i2c_bus_get_internal_bus_handle(s_bus);
    ESP_RETURN_ON_FALSE(s_internal != NULL, ESP_FAIL, TAG, "internal bus handle missing");

    if (s_bus_mutex == NULL) {
        s_bus_mutex = xSemaphoreCreateMutex();
        ESP_RETURN_ON_FALSE(s_bus_mutex != NULL, ESP_ERR_NO_MEM, TAG, "mutex create failed");
    }

    ESP_LOGI(TAG, "I2C bereit (I2C%d, SDA=%d, SCL=%d)",
             SENSOR_I2C_EXT_PORT, SENSOR_I2C_EXT_SDA_GPIO, SENSOR_I2C_EXT_SCL_GPIO);
    return ESP_OK;
}

i2c_bus_handle_t i2c_bus_get(void)
{
    return s_bus;
}

i2c_master_bus_handle_t i2c_bus_get_internal(void)
{
    return s_internal;
}

void i2c_bus_lock(void)
{
    if (s_bus_mutex) {
        xSemaphoreTake(s_bus_mutex, portMAX_DELAY);
    }
}

void i2c_bus_unlock(void)
{
    if (s_bus_mutex) {
        xSemaphoreGive(s_bus_mutex);
    }
}

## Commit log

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2026-02-13 refactor(sensorboard): WiFi dauerhaft aktiv, IMU dynamische Abtastrate
    Architektur-Umbau: WiFi + HTTP-Server starten beim Boot statt
    on-demand per RS485-Kommando.
    Änderungen:
    - app_main.c: sensor_wifi_init() + sensor_http_start() beim Boot
    - rs485_modem.c: level_start/stop steuern nur noch BNO055 Fast-Mode
    (bno055_app_request_fast) statt WiFi an/aus
    - sensor_http.c: /api/imu ruft bno055_app_request_fast(2000, 500)
    bei jedem Request → Sensor bleibt schnell solange horizon.html pollt,
    fällt auf 5s zurück wenn kein Client mehr da ist
    - sensor_wifi: Auth-Failure-Callback → RS485 fragt Display nach Passwort
    (wifi_pass_request), Void-Wrapper für Signatur-Kompatibilität
    - rs485_mo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
    [app_main.c]
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2026-02-17 Sensorboard: BNO055 Achsen-Mapping korrigiert und Kalibrierung verbessert
    - Kritischer Bugfix in bno055.c: AXIS_MAP_SIGN Register-Berechnung korrigiert
    - Achsen-Mapping: POSITIVE_Z→X, NEGATIVE_Y→Y, POSITIVE_X→Z (Right-Handed)
    - Kalibrierung: Schwellwert auf SYS=3 geändert, Auto-Restore bei SYS≤1
    - GPIO-Kommentare in sensor_config.h korrigiert (ADC-Kanäle)
    [bno055.c, sensor_config.h, womo_config.h]
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2026-02-18 Sensorboard: Gas/Tank NVS-Persistenz, ADC-Korrektur, Code-Cleanup, README neu
    - Gas-Zustand (Verbrauchsraten) wird jetzt per NVS gespeichert (Namespace: gas_state)
    - Gas-NVS wird bei Tare und Flaschentausch geleert
    - ADC-Kanäle korrigiert: CH3/GPIO4=Batt1, CH4/GPIO5=Batt2, CH0/GPIO1=Tank1, CH1/GPIO2=Tank2
    - Spannungsteiler 82kΩ/15kΩ implementiert (Faktor 97/15) für alle Kanäle
    - Tank-Prozent-Berechnung korrigiert (0-1V = 0-100%)
    - Toter Code entfernt: analog_log_task, analog_start_logging, analog_read_bat_gpio1_mv
    - Ungenutzte Includes entfernt (nvs_flash.h, semphr.h, freertos/task.h)
    - README.md neu erstellt (Hardware, RS485-Protokoll, ADC, NVS-Namespaces)
    - Alte README_cn.md und _stat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
2026-02-18 feat: Meteoalarm-Integration mit GPS-Badge und Popup
    - womo_meteoalarm.{c,h}: Neues Modul für Meteoalarm-API
    - HTTP-Fetch für coordinates/{lat}/{lon}
    - CAP-JSON-Parsing: Severity, Headline, Region, Expires
    - Hintergrundtask mit 30-Min-Intervall (5-Min-Retry)
    - 60 s earliest_fetch nach Systemstart (TLS-Kollisionsvermeidung)
    - NTP-Sync-Gate: Fetch erst nach gültiger Systemzeit
    - Use-after-free-Fix: cJSON_Delete nach allen Fallback-Loops
    - Fallback-Regionserkennung: Minor-Warnungen, info[].areaDesc
    - main.c:
    - Meteoalarm-Badge am Wetter-Icon (Severity-Farbe, Anzahl)
    - Touch-Popup: Standort/Region + Warnliste + meteoalarm.org
    - Region-Fallback: API-Region → Geocode-Orts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
    [main.c, womo_rs485_display.c]
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2026-02-19 Display: TLS-Fix, Geocode Nominatim, HTTP-Mutex
    TLS-Verbindungen (Wetter, Geocode, Meteoalarm) schlugen fehl wegen
    zu wenig internem SRAM (~39 KB frei, mbedTLS braucht ~50 KB).
    Fixes:
    - MBEDTLS_EXTERNAL_MEM_ALLOC=y: mbedTLS nutzt jetzt PSRAM (4.8 MB frei)
    - ISRG Root X1 PEM direkt eingebettet statt crt_bundle_attach für
    Wetter + Geocode (spart RAM, reicht für Let's Encrypt)
    - Meteoalarm bleibt bei crt_bundle_attach (HARICA CA)
    - HTTP-Mutex: serialisiert TLS-Sessions gegen Heap-Engpässe
    - Geocode: Nominatim statt open-meteo (kein Reverse-Endpoint)
    Parser: address.city/town/village + address.state
    - GPS-Zeitsync: Plausibilitätsprüfung year >= 2024
    - Router-IP in womo_router_uci.h zen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
    [main.c]
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2026-02-19 README: Projektbeschreibung ohne technische Details
    Beschreibt das WoMo-Home-System aus Nutzersicht:
    - Motivation und Problemstellung
    - Überwachte Betriebsdaten (Energie, Gas, Wasser, Klima, Navigation)
    - Systemaufbau (Sensorboard, Display, Router)
    - Warum Eigenbau (Genauigkeit, Prognosen, Open Source)
    Technische Details bleiben in den Unter-READMEs und docs/.
2026-02-19 Fix: Drucktrend-Strings RS485, README aktualisiert, .gitignore erweitert
    - rs485_modem.c: press_trend_1h/3h → press_trend_state + press_trend_hpa_h
    Strings korrigiert: falling→fall_slow, rising→rise_slow (Display-Kompatibilität)
    Bevorzugt 3h-Trend, Fallback auf 1h
    - README.md: Pins korrigiert (RS485: GPIO9/10/8), NVS-Namespaces aktualisiert,
    Steuer-GPIOs und Projektstruktur ergänzt
    - .gitignore: Logos, Datasheets, gas_bottle-Tests, alte Workspace-Datei
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2026-02-20 Fix: BSEC NVS Einheiten-Bug, Intervall 30 min; Spec ctrl-Topic bereinigt; Walter→Sensorboard
    - bme680_sensor.c: now_ns/1000 korrekt als now_us verwenden (war ns vs µs Vergleich
    → speicherte alle ~3 s statt alle 10 min → IAQ-Sprung nach Reboot)
    - BSEC_STATE_SAVE_INTERVAL: 10 min → 30 min
    - copilot-instructions.md: ctrl-Topic wifi_target/wifi_active/lte_target/lte_active
    entfernt (Sensorboard kennt Router-Zustand nicht; Display pollt Router direkt)
    - bat-Topic: soc? entfernt (nicht implementiert, nur Rohspannung)
    - Display: 'Walter' → 'Sensorboard' in Kommentaren, Log-Meldungen und Locale-Strings
    [main.c, womo_rs485_display.c]
2026-02-21 Feat: GasBee – ESP32-C3 Mini BLE Gaswage Grundgerüst
    Neues Teilprojekt firmware/gasbee/ für ESP32-C3 Mini:
    - CMakeLists.txt + sdkconfig.defaults (esp32c3, NimBLE, PM)
    - gasbee_config.h: HX711 Pins/Kalibrierung, BLE UUIDs, Gas-Parameter
    - ble_gas.c/h: NimBLE GATT Server mit 4 Characteristics
    Weight_kg (Notify), Gas_pct (Notify), Net_gas_kg (Notify), Tare (Write)
    - app_main.c: HX711 Messung, Gas-Berechnung, BLE Notify, NVS Tare-Persistenz
    - components/hx711: Symlink auf sensorboard/components/hx711
    - womo-sensor.code-workspace: GasBee-Ordner + Build/Flash/Monitor-Tasks
    Fix: Drucktrend – 1h überschreibt 3h bei abweichender Richtung (rs485_modem.c)
    Fix: Drucktrend – last_sample_us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
    [app_main.c, gasbee_config.h]
2026-02-21 Fix: GasBee – Bugfixes Erstinbetriebnahme ESP32-C3
    - ble_gas.c: esp_nimble_hci_and_controller_init() entfernt (ESP-IDF v5 obsolet)
    esp_nimble_hci.h-Include entfernt, nimble_port_init() reicht
    - app_main.c: hx711_read() -> hx711_read_data() (korrekter Funktionsname)
    - app_main.c: HX711-Init mit Retry-Schleife statt ESP_ERROR_CHECK/abort()
    -> stabiler Start auch ohne angeschlossene Waage
    - gasbee_config.h: DOUT GPIO2->GPIO4, SCK GPIO3->GPIO5
    (GPIO2 ist Strapping-Pin am C3, kann Boot stören)
    - womo-gasbee.code-workspace: Neue dedizierte Workspace-Datei
    mit esp32c3-Target, /dev/ttyUSB0, riscv32-Compiler
    [app_main.c, gasbee_config.h]
2026-02-21 Fix: GasBee – Kalibrierung + Diagnose HX711
    - gasbee_config.h: Kalibrierung mit echten Messwerten (21.02.2026)
    offset=-278300, scale=0.00003999 (18 kg / 450090 LSB)
    DOUT=GPIO4, SCK=GPIO5 (GPIO2 war Strapping-Pin)
    - app_main.c: Pull-Up auf DOUT aktiviert (floating-Schutz)
    - app_main.c: Diagnose raw=0 + Min/Max pro Messzyklus im Log
    [app_main.c, gasbee_config.h]
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2026-02-21 feat: Threshold-Settings, Locale-Fix, Sunset-Textfarben, Ducato-Bug
    - Settings-Modal: Grenzwerte Gas/Frisch/Grau mit +/-5%-Buttons, NVS-Persistenz
    - Locale: Threshold-Abschnitt DE/EN lokalisiert (5 neue STR_THRESH_*-IDs)
    - Modals: lv_obj_del_async() -> kein 1s-Schliess-Haenger mehr
    - Theme: Ducato bleibt grau bei temp. Zeitfehler (kein DAY-Reset)
    - Theme: Textfarben bei SUNSET/SUNRISE/NIGHT korrekt weiss (theme_mode_is_daylike)
    [main.c]
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2026-02-26 feat: RTC-Status-Popup (Long-Press Datum), WiFi-Reconnect-Fix
    Display:
    - Long-Press auf Datumslabel zeigt Zeitquellen-Popup:
    Sync-Quelle (NTP/GPS/RS485/RTC), Sync-Alter, RTC-Batteriestatus
    (aus Sensorboard ctrl-Topic: rtc_bat_low, rtc_bat_switched)
    Auto-Hide nach 8s, Tag/Nacht-Theme-aware
    - WiFi-Reconnect-Bug behoben: esp_wifi_start() ESP_ERR_WIFI_CONN /
    ESP_ERR_INVALID_STATE toleriert statt Abort; portMAX_DELAY durch
    15s-Timeout ersetzt; Retry-Intervall 180s → 30s
    - Verbessertes WiFi-Diagnose-Logging (reason-Code, retry n/max)
    - womo_rs485_display: RS485 ts-Plausibilitätsprüfung (Uptime vs. Epoch)
    [app_main.c, main.c, sensor_config.h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]
2026-03-01 sensorboard: GPIO-Pinbelegung korrigiert (12V EIN=GPIO11, 12V AUS=GPIO12, Multimedia=GPIO13)
    [sensor_config.h]
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2026-03-06 feat(display/lvgl9): Phase 1 – esp_lvgl_port v2, LVGL v9, lvgl_port Rewrite
    - idf_component.yml: lvgl ^9 + espressif/esp_lvgl_port ^2 (war: lvgl v8 lokal)
    - lvgl_port.h: komplett neu, schlanke API – womo_lvgl_port_init(),
    lvgl_touch_set_wake_cb(), lvgl_touch_set_fast_mode(); lock/unlock kommen
    jetzt aus esp_lvgl_port.h (uint32_t timeout, 0 = warte unbegrenzt)
    - lvgl_port.c: 660 → ~185 Zeilen; Display via lvgl_port_add_disp_rgb()
    (Bounce-Buffer + Avoid-Tearing); Touch: eigener lv_indev mit LVGL-v9-API
    (lv_indev_create/set_read_cb) für Wake-Callback + adaptives Sampling
    - waveshare_rgb_lcd_port.c: rgb_lcd_on_vsync_event + Callback-Registrierung
    entfernt (esp_lvgl_port übernim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
    [lvgl_port.c, lvgl_port.h, main.c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]
2026-03-06 fix(display/lvgl9): Phase 1 Runtime-Fixes – SPIRAM, Speicher, PNG-Cache
    - LVGL-Task-Stack auf MALLOC_CAP_INTERNAL (SPIRAM-Stack + NVS → Assertion-Crash)
    - LVGL-Malloc auf LV_USE_CLIB_MALLOC (malloc/free, kein TLSF-Pool-Limit)
    - LV_CACHE_DEF_SIZE=2MB: PNG (Ducato 800×480, Icons 64×64) einmalig dekodiert,
    Folge-Redraws sind Cache-Hits ohne Decoder-Blockierung → kein WDT mehr
    - LV_IMAGE_HEADER_CACHE_DEF_CNT=8
    - BOUNCE_BUFFER_HEIGHT 10→4 (12.5KB DMA, passt in 32KB internen Reserve-Pool)
    - SPIRAM_TRY_ALLOCATE_WIFI_LWIP=y, SPIRAM_MALLOC_ALWAYSINTERNAL=0
    - LVGL-Task-Stack 6KB→16KB (lodepng braucht ~12KB Tiefe)
    - LV_USE_LODEPNG=y (PNG-Decoder für RAW_ALPHA-Bilder)
    - TASK_WDT_TIMEOUT_S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
    [lvgl_port.c, main.c, waveshare_rgb_lcd_port.c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]
2026-03-07 feat(display): Boot-Optimierungen, Theme-Fix, WeatherCache, WiFi-Async
    - WiFi async connect: parallel zu Display-HW+UI, spart ~1.5s
    - Bootzeit <4s (vorher 6-7s): -O2, Bootloader WARN, 150ms delay
    - Weather icon: lv_image_cache_drop() fix (stale LVGL cache bug)
    - Weather/Meteoalarm: Reconnect nach WiFi-Trennung korrekt
    - SUNRISE theme: weißer Ducato + schwarze Texte (war grau)
    - Perf-Monitor: 2 Zeilen FPS+CPU (ohne ms-Timing)
    [main.c]
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2026-03-08 feat(display): Locale-Vollständigkeit, Fenster-Stacking-Fix, UI-Feintuning
    - Locale (DE/EN): Tank Frisch/Grau, Gas Vorne/Hinten, Einstellungen,
    Kfz, Schliessen + Sofortaktualisierung bei Sprachwechsel
    - Settings-Modal: Titel + Close-Button sofort lokalisiert (s_title_lbl,
    s_close_lbl als statische Pointer in settings_locale_cb)
    - Fenster-Stacking: Konnektivitäts-Close schließt Router-LEDs-Modal mit
    (womo_router_leds_modal_close() in destroy_modal)
    - Perf-Monitor: Mindestbreite 80px + rechtsbündiger Text (kein Flackern)
    - Indoor-Luftwerte: 5px nach rechts verschoben
    - tank_info_label: Format-String lokalisiert (Frisch/Fresh)
    [main.c]
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2026-03-17 feat(display): Meteoalarm-Warnungen im Forecast-Modal, Log-Konfiguration, Ducato-Fix
    - display_config.h: Zentralisierte Log-Level-Konfiguration (wie sensor_config.h)
    - main.c: esp_log_level_set() für alle Module aus display_config.h
    - main.c: Ducato-Bild-Fix (LVGL Cache Poisoning) – separate img_dsc_day/night
    - womo_forecast_modal: Neue Meteoalarm-Warnsektion unterhalb der 5-Tage-Spalten
    (Trennlinie, Header-Label, bis zu 3 Warnzeilen mit Severity-Dot + Text, '+N weitere...')
    - womo_forecast_modal_set_warnings() API + Live-Update wenn Modal offen
    - main.c: set_warnings() in weather_widget_click_cb + meteoalarm_update_cb verknüpft
    [display_config.h, main.c]
2026-03-17 fix(sensor): RS485, BLE, RTC – div. Korrekturen
    [app_main.c]
2026-03-20 tools/router-webui: LTE CGI, Scan-Schließen-Button, deploy Fixes
    - LTE: dediziertes /cgi-bin/lte CGI (gsmctl direkt, kein ubus file/exec)
    RSSI/RSRP/SINR zeilenweise geparst, PATH explizit gesetzt
    - ubus CGI-Proxy: PATH gesetzt, Tempfile statt stdin-Pipe (uhttpd-Kompatibilität)
    - Deploy: einmaliges Passwort (SSH + WebUI), sshpass-Support mit Fallback
    Passwort-Test lokal via curl (kein SSH-Escaping bei Sonderzeichen)
    Deploy-Test erkennt CGI-Proxy-Fehler korrekt
    - WLAN-Scan: Button wechselt zu 'Scan schließen' nach Scan,
    Auto-Clear nach 3 Aktualisierungen
    - refreshAp/refreshWifi: parallele ubus-Calls für kürzere Ladezeit
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2026-03-29 fix(sensorboard): GPIO7 Hi-Z im Sleep/Boot, GPIO-Fixes, HW-Doku
    Display-MOSFET Q4 (AO3401A P-Kanal):
    - GPIO7 beim Boot und Deep Sleep als Hi-Z (Input) statt OUTPUT HIGH
    - R21 (100k, Source→Gate) hält Gate passiv bei ~5V → Vgs=0V → FET sperrt
    - OUTPUT HIGH (3,3V) erzeugte Vgs=−1,7V → AO3401A leitete → ~300mA Querstrom
    - set_output_gpio() in deep_sleep.c entfernt (nicht mehr verwendet)
    - gpio_hold_en/dis für GPIO7 entfernt (R21 übernimmt passive Haltung)
    GPIO-Initialisierung app_main:
    - GPIO7 und GPIO13 getrennte gpio_config-Blöcke mit korrekten Modi
    - GPIO13 (N-MOSFET Radio): OUTPUT LOW (unverändert)
    Hardware-Änderungen dokumentiert:
    - BNO055 direkt auf Platine (kein Break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
    [app_main.c, deep_sleep.c, sensor_config.h]
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2026-03-29 feat(sensorboard/hal): Buzzer-Treiber hinzugefügt (buzzer.c/h)
    [buzzer.c]
2026-03-30 fix(sensorboard): Code-Review Bugfixes, Credentials-Trennung, Cleanup
    - BNO055: s_restore_attempted entfernt – Kalibrierung kann nach
    Verlust zur Laufzeit erneut aus NVS geladen werden
    - HX711: Snapshot-Schreiben jetzt innerhalb des Mutex (Race Condition)
    - Tank: Instantane Rate durch EMA-Glättung ersetzt (analog zur
    Gas-Berechnung), neuer Min-Abstand SENSOR_TANK_RATE_MIN_DT_SEC
    - Credentials: SSID/Passwort aus womo_config.h in separates
    womo_credentials.h ausgelagert (.gitignore), .example als Template
    - Display Kconfig: Hardcoded Credentials-Defaults durch "" ersetzt
    - Typo: SENSOR_BOARD_NAME "WROMM" → "WROOM"
    - Doku: sensor_http.h Kommentar aktualisiert (level_start/stop veralt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
    [sensor_config.h, womo_config.h]
2026-04-03 feat(display): Forecast-Layout, DST-Fix, Innen-Luft-Toggle, NVS-Crash-Fix
    - MaterialSymbolsOutlined Font (49 Glyphen, 16px): korrekte Icons fuer
    wb_sunny, arrow_up/down, water_drop, air
    - Forecast-Modal: Icons + Divider in Spalten, WARN_Y0 korrigiert,
    COL_CONTENT_Y0/H angepasst
    - DST-Bug in womo_sun_calc: tm_gmtoff -> POSIX-kompatibler difftime-Workaround
    - womo_time: update_location() + get_sun_times() kapseln womo_sun_calc
    (main.c ruft sun_calc nicht mehr direkt auf)
    - router_poll_task: Stack von PSRAM auf internem RAM (xTaskCreate statt
    xTaskCreateWithCaps) - behebt NVS/Flash-Cache-Assert
    - Innen-Luftwerte: Long-Press togglet zwischen Vollansicht (IAQ/CO2/bVOC)
    und Einfachansich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
    [buzzer.c, display_config.h, lvgl_port.c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]
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2026-04-07 hardware(sensorboard): Zwei neue 12V-Schaltausgänge (Pumpe, Licht) hinzugefügt, Aufräumen und Fehler des Vorgänger-Boards behoben
    [Sensorboard.kicad_pcb, Sensorboard.kicad_sch]
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2026-04-23 feat/fix: BSEC 3.3V-Config, I2C-Recovery, Batt-Kali; Display + Hardware aktualisiert
    - I2C Bus-Recovery (9 SCL-Pulse) für hängende Slaves (SDA klemmt LOW)
    - BSEC 3.3V Pflicht-Konfiguration (bsec_config_33v_3s_4d) + HeatSource-Input
    (Standard-BSEC nutzt 1.8V – ohne Config sind IAQ-Werte dauerhaft falsch)
    - Batterie-Kalibrierungsoffset 200 mV (BATT1 + BATT2)
    - BME680 Board-Temperaturoffset 4.0 °C (SENSOR_BME680_TEMP_OFFSET_C)
    - IAQ Accuracy-basiertes sofortiges State-Speichern (Bosch-Empfehlung)
    - Dashboard HTML: Cache-Control no-store für HTML-Seiten; aktualisiertes dashboard.html
    Display: Fonts (material_24 neu), rs485, main.c, display_config aktualisiert;
    LVGL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
    [SensorBee.kicad_pcb, SensorBee.kicad_sch, Sensorboard.kicad_pcb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]
2026-04-30 Stabilize display boot path and rebalance memory
    [display_config.h, main.c, sensor_config.h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]
2026-05-05 feat(website): Inhalte und Systemübersicht aktualisiert
    - Architektur korrigiert: Display sendet nur Befehle per RS485, schaltet nicht selbst
    - Sensorboard als ausführende Einheit mit Schaltausgängen und MOSFET für Display
    - Buzzer dem Display zugeordnet; EBL auf EBL262-3 korrigiert (LT 45X = Panel)
    - Kaufen-Sektion als Produktgrid (Fremdprodukte + Eigenentwicklungen mit Preisen)
    - Kontaktformular nach FAQ verschoben
    - Web-Flasher-Ressource und FAQ-Eintrag ergänzt
    - Systemübersicht SVG hinzugefügt (Router, Display, Sensorboard, SensorBee, Sensoren)
2026-05-05 fix: Verwaisten Submodul-Eintrag entfernen
    archive/firmware-walter/walter-esp-idf war ohne URL im Index eingetragen
    und hat den Netlify-Build blockiert.
2026-05-05 fix(website): netlify.toml an Repo-Wurzel verschoben
    Netlify sucht die Konfiguration immer im Root, nicht im Unterverzeichnis.
2026-05-08 feat(display): elec-Topic, Theme-Timing, TLS-Fix, PSRAM-Crash
    - RS485 elec-Topic: INA226 Strom/Leistung parsen + zwischen Batterien anzeigen
    (3-zeiliges Widget: Titel, U/I, P; entfällt wenn nc:true oder kein Empfang)
    - Theme-Boot-Regression: WOMO_CIVIL_TWILIGHT_MINUTES 24 → 45 min,
    damit 20:13 Uhr beim GPS-Update sofort als SUNSET erkannt wird
    statt ~10 min lang fälschlich als DAY
    - Farbverlauf Dämmerung auf 45 Einträge erweitert (Midnight Blue → Sky Blue)
    - wifi_autoretry_task: Stack von PSRAM → SRAM (MALLOC_CAP_INTERNAL),
    verhindert Assert in spi_flash_disable_interrupts_caches_and_other_cpu
    - Meteoalarm TLS: GEANT TLS RSA 1 PEM direkt eingebunden (harica_root_pem.h)
    st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
    [display_config.h, main.c, womo_rs485_display.c]
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2026-05-18 fix(sensorboard): INA226 Shunt 10 mΩ, Batterie-Kalibrierung neue Platine
    - INA226: SENSOR_INA226_SHUNT_MOHM 1 → 10 (verbauter Shunt 10 mΩ)
    - Batterie SCALE: 1.354 → 1.012 (neue Platine, Anzeige 17,4 V bei 13,0 V)
    Alter SCALE war Ausreißer durch Q3-Defekt auf Vorgängerplatine
    - BNO055 antwortet nicht (fehlt im I2C-Scan 0x40/0x68/0x76/0x77) → Hardwarefehler
    [sensor_config.h]
2026-05-18 fix(sensorboard): GPIO7-Logik invertiert (Q5-Treiber), INA226 MAX_CURRENT 3 A
    Neue Platine: N-Kanal 2N7002 (Q5) als Treiberstufe vor P-Kanal AO3401A (Q4).
    - GPIO7 HIGH = Display EIN (Q5 leitet → Q4-Gate LOW → AO3401A leitet)
    - GPIO7 LOW/Hi-Z = Display AUS (Q5 sperrt → R21 zieht Q4-Gate auf 5V)
    - OUTPUT HIGH war auf alter Platine verboten, ist jetzt korrekte EIN-Schaltung
    - Deep Sleep: RTC OUTPUT LOW + Hold (statt Input + Hold)
    - Boot: sofortiges OUTPUT LOW statt Hi-Z (explizit AUS vor pwr_12v_on_early)
    - INA226 MAX_CURRENT_A: 100 → 3 (Display+Board inkl. Relais, max ~2 A, LSB=91 µA)
    - CLAUDE.md Constraint aktualisiert
    [app_main.c, deep_sleep.c, sensor_config.h]
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2026-06-15 fix(sensorboard): PCF8523 Battery Switch-over aktivieren (PM-Bits auf 000)
    Nach Power-On-Reset ist Control_3 = 0xE0 (PM=111 = Battery Switch-over
    deaktiviert). Die PM-Bits wurden bisher nur eingelesen aber nie auf 000
    gesetzt, obwohl der Kommentar das beschrieb. Dadurch verlor der RTC beim
    Ausschalten die Spannung, der Oszillator stoppte und das OS-Flag wurde
    bei jedem Einschalten neu gesetzt — trotz voller Knopfzelle (2,9 V).
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2026-08-20 feat(sensorboard): Ruuvi-Batteriespannung aus DF5-Frame auswerten
    Byte 15-16 des Ruuvi Data Format 5 (Power Info) enthalten die
    11-Bit-Batteriespannung (+1600mV Offset), bisher ungenutzt. Wird
    jetzt als battery_mv/battery_valid im Snapshot geführt und im
    Ruuvi-Fallback der Topics bme_in/bme_out als batt_mv mitgesendet.
    Doku (README, CLAUDE.md, systemPatterns.md) korrigiert das veraltete
    "bme"-Topic auf die tatsächlichen bme_in/bme_out-Topics.
    [espnow_modem.c]
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2026-09-17 fix(router): RUTX11-LAN-Subnetz auf 192.168.55.1 geändert
    Kollision mit dem Heimnetz "Solaris" (nutzt ebenfalls 192.168.10.0/24):
    bei aktivem WireGuard-Tunnel zum Heimnetz war der Wohnmobil-RUTX11 nicht
    mehr erreichbar, da die vom VPN-Peer mitgebrachte Route für
    192.168.10.0/24 gegen die lokale Route zum Router gewann.
    Router-seitig auf 192.168.55.1 umgestellt, Code an allen Stellen
    nachgezogen (Kconfig-Default, Fallback-Define, geteilte Config für
    Sensorboard).
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2026-10-04 feat(router-webui): Datenvolumen-Anzeige (pass.telekom.de) + IP-Fix
    Neue Anzeige im LTE-Panel des Router-WebUI-Tools: fragt das Restvolumen
    des aktuellen Congstar-Datenpasses über pass.telekom.de ab (IP-Erkennung
    über die LTE-Schnittstelle, kein Login nötig, laut Congstar-Support
    "verbraucht kein Datenvolumen").
    - /etc/womo/datapass.sh (neu, deploy.sh): holt + parst den Wert, schreibt
    /etc/womo/datapass.json (atomar, mit Zeitstempel) - analog zum
    bestehenden poll.sh/status.json-Muster.
    - Cron alle 30 min + einmaliger Aufruf 60s nach Boot (rc.local), damit
    die Anzeige ohne manuelles Nachfragen aktuell bleibt.
    - Seite zeigt beim Öffnen sofort den gecachten Stand (/datapass.json),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
2026-10-17 fix(sensorboard): BLE-Scan-Fenster 100 %, HX711-Warnung nur einmal, GAS-Log mit Quelle
    - SENSOR_BLE_SCAN_WINDOW = Intervall (50/50 ms): mit 30/50 ms kamen nur
    2/10 GasBee-Pakete pro Messzyklus an, jetzt 4-5/10; ESP-NOW unverändert
    - HX711 ohne Modul (GasBee-Betrieb): Ausfall einmal als WARN, Wiederkehr
    als INFO, Wiederholungen nur DEBUG statt 3 Warnungen alle 10 s
    - Log-Zeile GAS zeigt Quelle (hx/ble) und Netto statt Nennfüllmenge
    - gas_source: Veraltungsprüfung µs/ms korrigiert (galt nach 0,61 s als alt)
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2026-10-18 fix(sensorboard): Tank-Rate nach Neustart nicht mehr eingefroren
    tank_state speicherte den Laufzeit-Zeitstempel (esp_timer) im NVS. Nach
    einem Neustart war die neue Laufzeit kleiner, dt negativ und die Rate
    blieb stehen, bis die Laufzeit den alten Wert überholte. Beim Laden wird
    last_ts_us jetzt verworfen, der erste Messwert ist die neue Basis.
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2026-10-18 fix(sensorboard,display): Scan-Listen als ein Frame pro Gerät
    gasbee_scan mit zwei GasBees war 301 Byte und damit größer als
    WOMO_ESPNOW_MAX_PAYLOAD (250). Der Frame wurde verworfen, das Display
    bekam keine Liste und GasBee 2 ließ sich nicht zuordnen. ruuvi_scan
    hatte dasselbe Problem ab drei Tags in Reichweite.
    Sensorboard: ruuvi_scan/gasbee_scan gehen jetzt als ein Frame pro
    Gerät (sid, idx, cnt; cnt 0 = nichts gefunden), ein Frame pro Durchlauf
    des TX-Tasks. Die Liste zeigt weiter alle Geräte (max. 8), zugeordnet
    wird explizit per MAC. GasBee-Feld seq heißt jetzt bee_seq
    (Kollision mit der Frame-seq).
    Display: womo_sensorboard.c setzt die Frames nach sid zusammen und
    liefert an d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
2026-10-19 feat(display): Einstellungs-Modal neu gegliedert, Texte über womo_locale
    - Tabs jetzt AP | Sensoren | Grenzwerte | System, AP ist Starttab
    - Sprache und RTC-Info in den System-Tab verschoben (zwei Spalten:
    Töne + Sprache | Zeit / RTC)
    - „RTC / Temp / Gas“ heißt jetzt „Sensoren“ (Ruuvi + GasBee), Layout
    nach oben gerückt, Platz für weitere Sensoren
    - Tab-Titel, Abschnitte, Zeilen, Buttons und Zeit-Infos über
    womo_locale (DE/EN), Live-Update bei Sprachwechsel
    (lv_tabview_set_tab_text)
    - Ton-Buttons lesen den Zustand aus dem Buzzer-Modul statt aus dem
    Button-Text
    - Doku (CLAUDE.md, README, Memory-Bank) nachgezogen
    Gebaut, noch nicht auf Hardware getestet.
    Co-Authored-B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

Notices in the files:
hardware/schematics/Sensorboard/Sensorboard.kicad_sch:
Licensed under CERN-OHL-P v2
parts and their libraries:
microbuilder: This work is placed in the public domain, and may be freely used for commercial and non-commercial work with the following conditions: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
